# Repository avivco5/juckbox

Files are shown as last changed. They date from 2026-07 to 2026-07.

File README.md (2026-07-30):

# Juckbox

An open-source, standalone touchscreen jukebox built on an ESP32-S3. No WiFi, no phone, no router — everything is controlled directly on the device's touchscreen: browse songs from a microSD card, play them through a real I2S audio path, pick from 12 UI themes, and play a couple of built-in games (Pinball, Air Hockey) without interrupting the music.

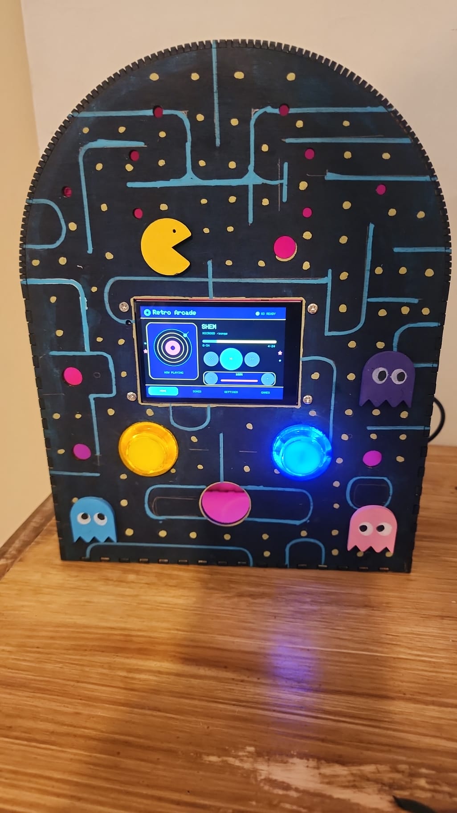
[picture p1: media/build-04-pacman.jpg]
Juckbox


This repository is the open-source release of the project: firmware, enclosure/cutting files, and a full bill of materials, so anyone can build their own.

## Repository layout

| Folder | Contents |
|---|---|
| [`firmware/`](firmware) | PlatformIO project — main ESP32-S3 firmware (display, touch, audio, songs, themes, games). Start here — see [firmware/README.md](firmware/README.md) for hardware pinout, build/flash instructions, and known limitations. |
| [`hardware/enclosure/`](hardware/enclosure) | 3D-printable/laser-cut enclosure files (`Cube.step`, `Cube.stl`, `jukebox.svg`) — base geometry generated with [Boxes.py](https://www.festi.info/boxes.py/), then modified |
| [`hardware/bom/`](hardware/bom) | Full bill of materials with AliExpress part links and prices — see [COMPONENTS.md](hardware/bom/COMPONENTS.md) for a plain-text version |
| [`extras/simon-says/`](extras/simon-says) | Standalone Simon Says PlatformIO project, a smaller side project built alongside the jukebox |
| [`design/`](design) | Concept art and case-design references used while designing the enclosure |
| [`ui-mockups/`](ui-mockups) | Standalone HTML previews of UI/theme mockups |
| [`media/`](media) | Photos and a demo video of finished builds |

## Gallery

Finished Pac-Man themed build, running with backlit arcade buttons

*Pac-Man theme, running*

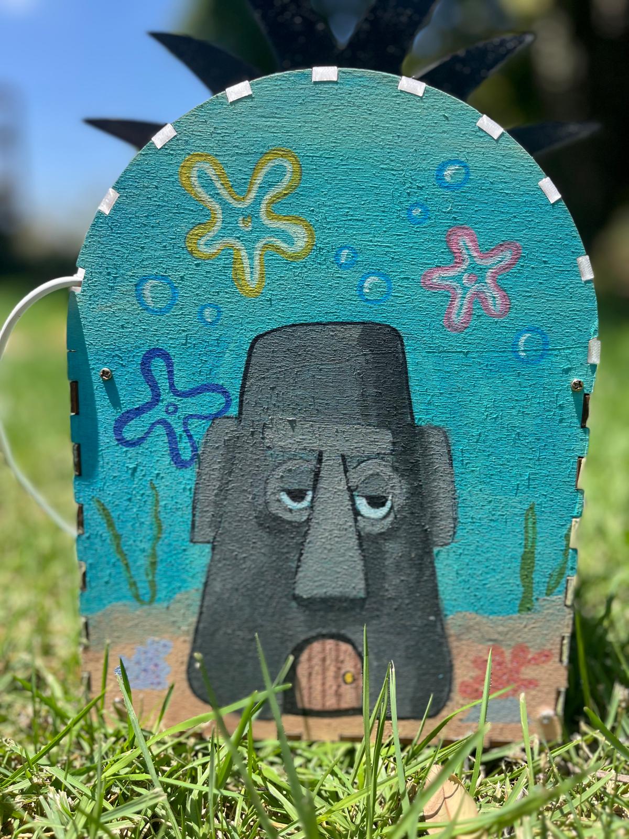
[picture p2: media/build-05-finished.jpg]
Finished build painted as Squidward's pineapple house


*Squidward's house theme*

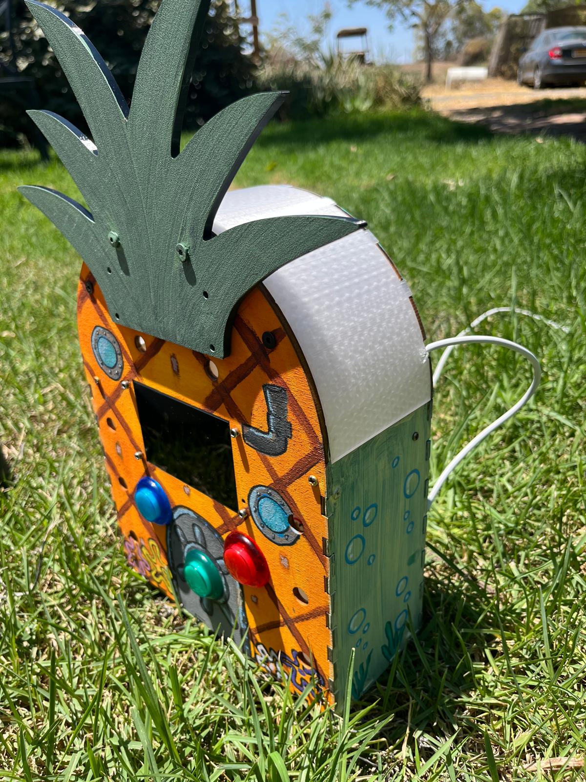
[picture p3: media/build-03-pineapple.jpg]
Pineapple-themed build in progress


*Pineapple theme, in progress*

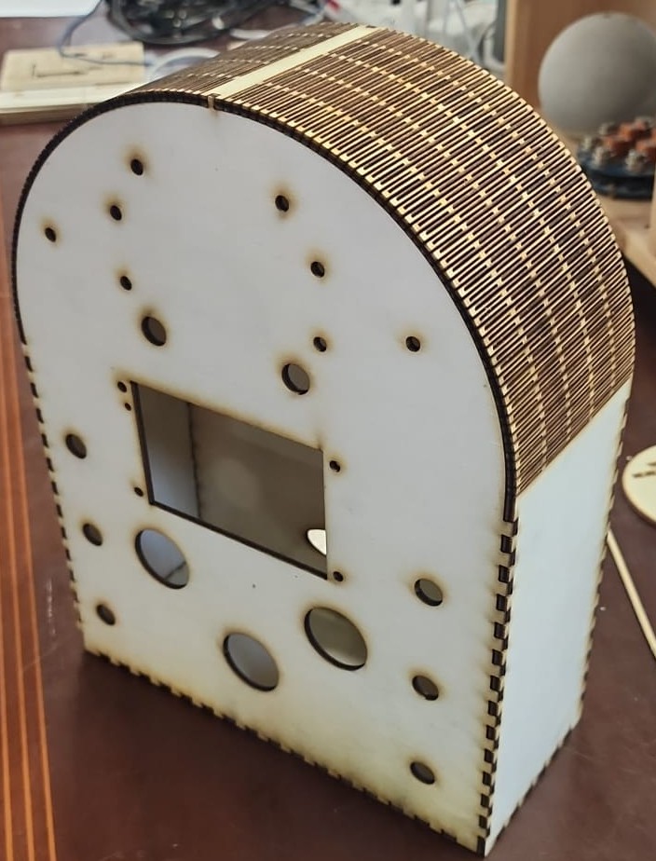
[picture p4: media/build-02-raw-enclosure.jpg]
Raw laser-cut enclosure before painting


*Raw laser-cut enclosure*

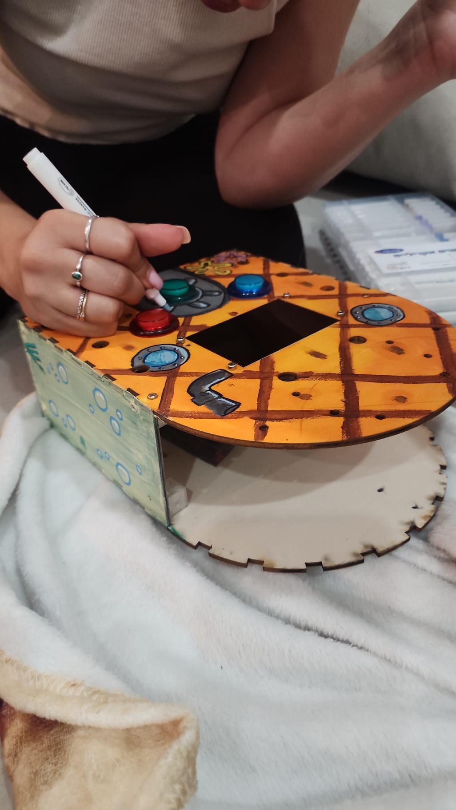
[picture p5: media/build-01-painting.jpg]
Hand-painting a laser-cut enclosure during a build workshop


*Painting at a build workshop*

### Demo video

[Watch the demo video](media/demo.mp4)

*(GitHub doesn't inline-embed video committed to a repo — click the image above, or go straight to [`media/demo.mp4`](media/demo.mp4), and GitHub's file viewer will play it.)*

## Getting started

1. Read [firmware/README.md](firmware/README.md) for the full hardware spec (ESP32-S3 module, display, touch, audio codec, SD card) and pin configuration.
2. Check [hardware/bom/](hardware/bom) for what to buy.
3. Print/cut the enclosure from [hardware/enclosure/](hardware/enclosure).
4. Build and flash the firmware with [PlatformIO](https://platformio.org/) — see the firmware README for exact steps.

## Affiliate Disclosure

Some purchase links in the [BOM](hardware/bom) may be AliExpress affiliate links (marked **Affiliate**). If you buy through a marked link, the project maintainer may receive a small commission at no additional cost to you. Affiliate links never change which component is recommended, and using them is entirely optional — every part in the BOM also lists its plain specification so you can search and buy it independently. See [hardware/bom/README.md](hardware/bom/README.md) for details.

## License

Licensed under the [GNU General Public License v3.0](LICENSE).

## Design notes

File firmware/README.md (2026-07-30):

# ESP32-S3 Touchscreen Jukebox

Standalone jukebox running on an ESP32-S3 with a 3.5" QSPI touchscreen, a microSD card slot, and a real I2S audio path (ES8311 codec + speaker amp). No WiFi, no phone, no router — everything is controlled directly on the device's touchscreen.

---

## What it does

| Feature | Status |
|---|---|
| Touchscreen UI (Home / Songs / Settings) | ✓ |
| List MP3 / WAV songs from SD card | ✓ |
| Play / Pause / Resume / Next / Previous | ✓ |
| Volume control (0–100, 5% steps) | ✓ |
| Real I2S audio playback (ES8311 codec) | ✓ |
| Elapsed-time / progress display (real song duration) | ✓ |
| Settings persist across power cycles (volume, repeat, shuffle, last song, theme) | ✓ |
| 12 selectable UI color themes, including a user-editable "Custom" theme (Settings → THEME) | ✓ |
| External PLAY/PAUSE and NEXT buttons | ✓ |
| RGB status LED (rainbow while playing, or always-on via Settings) | ✓ |
| Repeat (Off / One / All) and Shuffle | ✓ |
| Pinball + Air Hockey games (GAMES tab — no reflashing needed, music keeps playing) | ✓ |
| WiFi / web remote control | Removed (see [Legacy WiFi/Web Control](#legacy-wifiweb-control)) |
| Playlist support | Removed (see [Legacy WiFi/Web Control](#legacy-wifiweb-control)) |
| Physical buttons (MCP23017) | Future |

---

## Hardware

- ESP32-S3 development board with PSRAM (OPI, 8 MB embedded — N16R8 class module)
- 3.5" QSPI display, 480×320, ST77922-class panel controller
- Capacitive touch panel over I2C (CST9217/TDDI-style controller at address `0x55`)
- ES8311 I2C audio codec driving an I2S DAC path into a speaker amplifier
- MicroSD card (FAT32) wired in **SD_MMC 4-bit mode** (not SPI)

---

## Pin Configuration

Pins are currently **hardcoded per module** (display, touch, SD, audio each define their own pins at the top of their `.cpp` file) rather than centralized in `config.h` — see [Known Limitations](#known-limitations). To rewire the board, edit the file for the subsystem you're changing.

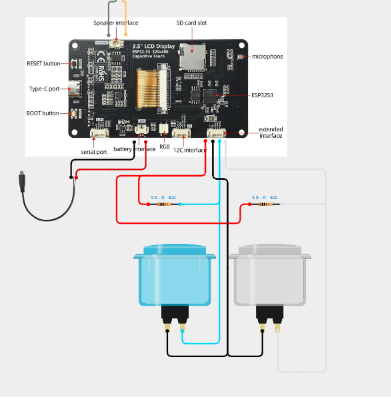
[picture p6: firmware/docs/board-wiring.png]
Board connector layout


### Display — QSPI ([src/DisplayDriver.cpp](src/DisplayDriver.cpp))

| Signal | GPIO |
|---|---|
| CS | 10 |
| CLK | 12 |
| D0 | 11 |
| D1 | 13 |
| D2 | 14 |
| D3 | 9  |
| Backlight | 41 |

### Touch — I2C ([src/TouchController.cpp](src/TouchController.cpp))

| Signal | GPIO |
|---|---|
| SDA | 38 |
| SCL | 39 |
| INT | 47 |
| RST | 48 |

I2C address: `0x55`. This bus is initialized once in `TouchController::begin()` and is reused by the ES8311 codec — `touchController.begin()` must run before `audioController.begin()` (already the case in [src/main.cpp](src/main.cpp)).

### SD Card — SD_MMC 4-bit ([src/SongLibrary.cpp](src/SongLibrary.cpp))

| Signal | GPIO |
|---|---|
| CLK  | 5 |
| CMD  | 4 |
| D0 | 6 |
| D1 | 7 |
| D2 | 2 |
| D3 | 3 |

### Audio — I2S + ES8311 codec ([src/JukeboxAudioOutput.cpp](src/JukeboxAudioOutput.cpp), [src/Es8311Codec.cpp](src/Es8311Codec.cpp))

| Signal | GPIO |
|---|---|
| MCLK | 17 |
| BCLK | 18 |
| WS | 21 |
| DOUT | 15 |
| PA enable | 1 (active-low) |

ES8311 codec I2C address: `0x18`. Codec is driven at 44.1 kHz / 16-bit stereo by default.

### External buttons ([src/main.cpp](src/main.cpp))

Both spare pins on the board's "Expansion Input Pins" connector (silkscreen IO45/IO46) are now used — IO38/39 are taken by the touch I2C bus, so there's nothing left over for a third button without an I2C GPIO expander (e.g. MCP23017 — see the "Future" row in the feature table above).

| Button | GPIO | Idle state | Wiring |
|---|---|---|---|
| PLAY/PAUSE | 46 | HIGH | Button to GND + **external ~10kΩ pull-up from GPIO46 to 3.3V** (GPIO46 is input-only with no internal pull-up — leaving this resistor out makes the pin float and read as repeated phantom presses) |
| NEXT | 45 | HIGH | Button to GND + **external ~10kΩ pull-up from GPIO45 to 3.3V** — wired the same way as PLAY/PAUSE on this build. **This is not the recommended wiring for this pin** — see the warning below. |

Both buttons use plain `INPUT` (not `INPUT_PULLUP`/`INPUT_PULLDOWN`) since neither pin's internal pull is reliable enough to depend on — the external resistor is mandatory, not optional, in both cases.

```
PLAY/PAUSE — GPIO46 (idle HIGH, pressed LOW)      NEXT — GPIO45 (idle HIGH, pressed LOW)
─────────────────────────────────────────────      ─────────────────────────────────────────────
                 3.3V                                                3.3V
                  │                                                   │
              ┌───┴───┐                                           ┌───┴───┐
              │ 10kΩ  │  external pull-up                         │ 10kΩ  │  external pull-up
              └───┬───┘                                           └───┬───┘
                  ├───────────────► GPIO46 (ESP32-S3, INPUT)          ├───────────────► GPIO45 (ESP32-S3, INPUT)
                  │                                                   │
              ┌───┴───┐                                           ┌───┴───┐
              │button │                                           │button │
              └───┬───┘                                           └───┬───┘
                  │                                                   │
                 GND                                                 GND
```

> **⚠️ Boot-reliability warning:** GPIO45 is sampled by the ESP32-S3's ROM bootloader at power-on to select flash voltage (3.3V vs 1.8V), and is *supposed* to idle LOW to avoid loading that strap — that's why earlier versions of this doc (and the code) had it wired with a **pull-down** instead (button to 3.3V, resistor to GND, idle LOW/press HIGH). This build wires it as pull-up instead (idle HIGH), matching the diagram above, because that's how the hardware was actually built. The firmware's button-reading code has been updated to match (`pressed = digitalRead(...) == LOW` for both buttons now — see `main.cpp`, `PinballMain.cpp`, `AirHockeyMain.cpp`), but **that's a software accommodation, not a fix for the underlying boot-strap risk**: the pin's voltage at boot is a hardware fact the bootloader reads before any of this code runs. If you see occasional failed/garbled boots, rewiring GPIO45 back to pull-down (and reverting the `== LOW` back to `== HIGH` for that pin in the three files above) is the actual fix.

### RGB status LED ([src/StatusLed.cpp](src/StatusLed.cpp))

| Signal | GPIO |
|---|---|
| Onboard RGB LED (WS2812-style, single data line) | 40 |

This pin is **not documented anywhere by the vendor** — it was found by physically probing the board with [src/RgbPinFinder.cpp](src/RgbPinFinder.cpp) (a one-off diagnostic, see its own PlatformIO env below). By default (`LedMode::WhenPlaying`) the LED cycles through a rainbow while a song is playing and turns off otherwise; the Settings page's **LED** toggle switches to `LedMode::Always` so it keeps cycling even when paused/stopped. Persisted as `ledmode=0/1` in `jukebox_settings.cfg`.

> Don't trust GPIO22/23/24/25 as candidates for anything — they don't physically exist on this ESP32-S3 chip (confirmed by hardware errors when tested). Don't assume GPIO48 drives the LED either — it matches the generic Arduino-ESP32 `esp32-s3-devkitc-1` board profile's default NeoPixel pin, but on this board GPIO48 is already the touch controller's reset line, confirmed unrelated to the LED.

---

## SD Card Folder Structure

```
SD card root/
├── songs/
│   ├── 001.mp3
│   ├── 002.wav
│   └── ...
└── jukebox_settings.cfg
```

`/songs` is created automatically on first boot if it doesn't exist. Only `.mp3` and `.wav` files are listed; the on-screen title is the filename without its extension.

`jukebox_settings.cfg` is a small plain-text key=value file (no JSON dependency) written by [src/JukeboxUI.cpp](src/JukeboxUI.cpp) whenever volume, repeat mode, shuffle, the selected song, theme, or LED mode changes, and read back on boot. The last song is only *selected*, never auto-played, on startup.

Song duration shown on the Home page and used for the progress bar is computed once per song during `SongLibrary::scan()` ([src/SongLibrary.cpp](src/SongLibrary.cpp)): exact for WAV (parsed from the `fmt`/`data` RIFF chunks), and an estimate for MP3 (file size ÷ bitrate of the first frame, assuming constant bitrate — will be off for VBR-encoded files since there's no Xing/VBRI header parsing).

---

## Install PlatformIO

1. Install [VS Code](https://code.visualstudio.com/)
2. Open Extensions → search `PlatformIO IDE` → Install
3. Restart VS Code

Or use the CLI:
```bash
pip install platformio
```

---

## Build and Upload

Open the `CODE/` folder in VS Code with PlatformIO, or use the terminal:

```bash
# Compile only (check for errors)
pio run

# Compile and upload firmware to the ESP32-S3
pio run --target upload

# Open Serial Monitor
pio device monitor
```

There is no web UI to upload anymore — `board_build.filesystem = littlefs` in `platformio.ini` and the `data/` folder are leftovers from the previous WiFi-controlled version and are not used by the current firmware (see below).

There are also alternate PlatformIO environments that build completely separate firmware images sharing only [src/DisplayDriver.cpp](src/DisplayDriver.cpp) — `rgb_finder` and `diagtest` are flashed *instead of* the jukebox (re-flash `esp32s3` afterwards to get it back):

```bash
pio run -e rgb_finder -t upload   # one-off: discover the RGB LED's GPIO (see above)
pio run -e diagtest -t upload     # assembly diagnostic: SD/song list + button press states
pio run -e pinball -t upload      # standalone pinball "cartridge" — not needed if you just want the GAMES tab
pio run -e airhockey -t upload    # standalone air hockey "cartridge" — same idea
pio run -e esp32s3 -t upload      # flash the real jukebox firmware again afterwards
```

### Games ([src/PinballGame.h](src/PinballGame.h) / [src/AirHockeyGame.h](src/AirHockeyGame.h))

Each game is playable two ways from the exact same code:

1. **From inside the jukebox** — the **GAMES** tab (see below), no reflashing needed. Music keeps playing in the background (`AudioController` isn't touched), since only the display and these two buttons are repurposed while a game is running.
2. **Standalone firmware** (`pio run -e pinball -t upload` / `-e airhockey -t upload`) — a dedicated "arcade cabinet" image with nothing else on it, for when you don't want the jukebox at all. Re-flash `esp32s3` afterward to get it back.

Both entry points per game (e.g. [src/PinballMain.cpp](src/PinballMain.cpp) for the standalone build, `JukeboxUI`'s `Page::Pinball` for the tab) just drive the same game class — the physics/rendering exist in exactly one place. `JukeboxUI::setButtonA()`/`setButtonB()` dispatch the two physical buttons to whichever game is currently active (`main.cpp` doesn't know or care which game that is).

**Pinball** — PLAY/PAUSE (IO46) = left flipper, NEXT (IO45) = right flipper. 3 balls per game; bumpers are worth 100 points each. When a ball drains past both flippers, the next one serves automatically; after the third, it's Game Over — press either button to restart.

**Air Hockey** — PLAY/PAUSE (IO46) = paddle up, NEXT (IO45) = paddle down, against a simple CPU-controlled opponent paddle. First to 5 points wins; press either button to restart after Game Over.

Both use simple fixed-timestep 2D physics (gravity/collision reflection for pinball, paddle-angle deflection for air hockey), not a physics engine — deliberately kept simple since [DisplayDriver::flush()](src/DisplayDriver.cpp) always pushes the *entire* 480×320 framebuffer (no partial/dirty-rect updates), which caps real-world frame rate at roughly 20–30 FPS regardless of how little changed — plenty for this kind of game, but a reason not to expect smooth 60 FPS on this display.

When played from the **GAMES** tab, an on-screen **EXIT** button (top-right) returns to the jukebox — the physical buttons can't do it themselves since they're busy being game controls while a game is running.

---

## Using the Touchscreen UI

The UI has four tabs along the bottom: **HOME**, **SONGS**, **SETTINGS**, **GAMES**.

- **HOME** — shows the current song, play/pause state, elapsed time, and has previous/play-pause/next buttons plus a volume +/- control.
- **SONGS** — paginated list (4 per page) of everything found in `/songs`. Tap a row to select and start playing it; tap **SCAN** to re-read the SD card after adding files; use `<` / `>` to page through the list.
- **SETTINGS** — a **REPEAT** button (tap to cycle OFF → ONE → ALL), a **SHUFFLE** toggle, and an **LED** toggle (AUTO = rainbow only while a song plays, the original behavior; ALWAYS = rainbow runs continuously even when paused/stopped); a **THEME** row with `<`/`>` arrows flanking it (step through themes one at a time, same as the Theme Menu's edge buttons) — tapping the theme name itself opens the full picker (see below). No volume control here — that's on **HOME** only, to leave more room for these.
- **GAMES** — **PINBALL** and **AIR HOCKEY** (see above). While a game is running, the jukebox's normal UI (top bar, bottom nav, themes) is replaced entirely by the game's own full-screen display; PLAY/PAUSE and NEXT become game controls instead of playback controls until you tap **EXIT**.

Repeat/shuffle only affect what happens automatically when a song finishes on its own (not the manual `<<`/`>>` buttons, which always go sequentially): **Repeat: One** replays the same song forever; **Repeat: All** advances to the next song (sequential, or random if Shuffle is on) and never stops on its own; **Repeat: Off** with Shuffle on still jumps to a random song when one ends; **Repeat: Off** with Shuffle off just stops, like before this feature existed.

Touch input is debounced in [src/main.cpp](src/main.cpp) to work around a touch-controller quirk where some CST9217/TDDI firmware revisions keep reporting the last coordinate after release; repeated taps are re-armed by time and by a "moved to a different control" check.

### Theme System

Tapping the bottom row of the **SETTINGS** page (labeled `THEME: <name>`) opens a scrollable **Choose Theme** screen listing all 12 themes; tapping a row applies it immediately and returns to Settings. The bottom nav bar stays visible on this screen too, so tapping **HOME**/**SONGS**/**SETTINGS** also exits it. Two arrow pills on the left/right edges of the screen step through themes one at a time (wrapping around) and apply instantly, for quickly browsing/previewing — the on-screen list auto-scrolls to keep the current pick visible.

- **Where themes are defined**: [src/Theme.h](src/Theme.h) / [src/Theme.cpp](src/Theme.cpp). Each themed design is six hand-picked colors (`background`, `panel`, `title`, `text`, `selected`, `border`); the rest of the palette (raised-surface tint, muted text, dark button text) is derived once at theme-switch time by `ThemeManager::buildDefinitions()`, so adding a new design theme only means one `makeTheme(...)` call. The exception is **Classic** — the app's original hand-tuned color scheme from before the theme system existed, kept as its own option since all nine of its colors are specified directly via `makeRawTheme(...)` rather than derived. New themes must be appended right before `THEME_COUNT` in `Theme.h`, never inserted earlier — the theme index is what's persisted to disk, so reordering existing entries would silently reassign everyone's saved theme.
- **Adding a static theme (the exercise for trainees)**: add one enum value right before `THEME_COUNT` in `Theme.h`, then one `makeTheme("Name", "Title Text", bg, panel, title, text, selected, border)` call in `ThemeManager::buildDefinitions()` in `Theme.cpp`. That's the entire change — `JukeboxUI.cpp` doesn't need to be touched, since every screen already reads colors through `themeManager.colors()`.
- **Custom theme (Settings → THEME → Custom row → EDIT)**: the one theme whose colors are chosen on-device instead of hardcoded. The editor screen (`JukeboxUI::drawThemeEditor`) shows the 6 color roles, each cycling through a shared 14-color swatch list (`kThemeSwatches` in `Theme.h`) via `<`/`>` — no free-form color picker, to keep the touch UI simple and stable. Selecting Custom applies it immediately (`ThemeManager::setCustomColors`, rebuilt the same way as any other theme) and every change is saved right away as `custom_bg`/`custom_panel`/`custom_title`/`custom_text`/`custom_selected`/`custom_border` (hex) in `jukebox_settings.cfg`, so it's remembered across restarts.
- **Default theme**: `ThemeManager::begin()` in `Theme.cpp` sets `_current = THEME_PINEAPPLE`. Change that line to change the factory default.
- **Persistence**: the selected theme is saved as `theme=<index>` in `jukebox_settings.cfg` alongside volume/repeat/shuffle (see `JukeboxUI::loadSettings()`/`saveSettings()`), so it survives power cycles.
- **Scope**: colors change everywhere via `themeManager.colors()`, plus small decorative accents on the **Home** page only (`JukeboxUI::drawThemeDecorations`) — no per-theme fonts or animations, so every theme stays equally fast and memory-safe. Each of the 10 box-design themes gets a matching 16×16 pixel-art icon (pineapple, star, robot head, rocket, skull, speaker, cassette, tree, gear, monster face — `iconPineapple`/`iconStar`/etc. in `JukeboxUI.cpp`), drawn twice (left of the album-art panel, right of the volume panel) via `Arduino_GFX::drawBitmap()`, recolored per theme by passing `theme.accent` as the draw color. A couple of themes add a tiny extra accent dot (bubble/coin/spark) from the remaining primitive helpers (`drawBubble`/`drawDot`/`drawCoin`). **Classic** and **Custom** intentionally have no icon — there's no fixed "vibe" to draw for either.
- **Where the icons come from**: hand-drawn with a one-off Pillow (Python) script — draw simple vector shapes (circle/polygon/line) at 160×160, downsample to 16×16 with Lanczos resampling, threshold to 1-bit. Not sourced from image files, so there's no asset pipeline to maintain; each icon is a 32-byte `static const uint8_t[]` array (1bpp, MSB-first, byte-packed rows — the exact format `drawBitmap()` expects). All 10 icons together cost ~320 bytes of flash. To change or add an icon, regenerate with the same technique (or hand-edit the hex bytes — each row is 2 bytes for 16 columns) and add a case to the `icon = ...` switch in `drawThemeDecorations()`.
- **Adapting the spec's button mapping**: the original theme-menu spec assumed physical NEXT/BACK/PLAY/SELECT buttons with long-press gestures. This hardware only has two buttons (PLAY/PAUSE on GPIO46, NEXT on GPIO45 — see [Pin Configuration](#pin-configuration)), both wired globally to playback in `main.cpp`. Rather than overload them with menu-navigation meaning, the theme menu is touch-only, reached from Settings as described above.

### Touch reliability — diagnostics only (active "fix" reverted)

The touch controller and the ES8311 audio codec share one I2C bus (GPIO38/39), and touch occasionally stops responding for no obvious reason. A first attempt at fixing this (I2C bus recovery + a periodic preventive rearm every 30s) made things **worse** — `Wire.begin()` isn't cheap, and re-running it on every accepted touch destabilized the I2C driver itself. That attempt was reverted.

What's left, in [src/TouchController.cpp](src/TouchController.cpp), is **passive only**: `readRegister()` logs `[Touch] I2C read failing` / `[Touch] I2C read recovered after N failed attempt(s)` on state transitions (not every poll, so it won't flood the log). If touch stops responding again, check the serial log for these messages — that'll tell us whether it's really an I2C-level failure before trying another fix.

---

## Known Limitations

- `src/config.h` is **not included by any file in the active build** (`platformio.ini`'s `build_src_filter`). All real pin/volume/storage constants are hardcoded in the relevant driver `.cpp` files instead — `config.h` is stale and should not be trusted as the source of truth for pins.
- No authentication or remote control of any kind — the device is controlled only via its own touchscreen.
- `next` / `previous` always wrap around the full song list found by the last `SCAN`; there's no shuffle or playlist concept anymore.
- Long song titles are truncated with `...` on screen; no Hebrew/RTL text rendering is attempted (the on-device UI is Latin/numeric only — Hebrew RTL lived in the removed web UI, see below).
- The RGB LED's color/brightness/animation speed are fixed constants in `StatusLed.cpp`, not exposed in the Settings UI.

---

## Legacy WiFi/Web Control

This repository still contains an earlier version of the jukebox that exposed a WiFi access point and a Hebrew RTL web UI (`/api/...` JSON endpoints, file upload, playlists):

- [src/WebServerManager.h](src/WebServerManager.h) / [.cpp](src/WebServerManager.cpp)
- [src/StorageManager.h](src/StorageManager.h) / [.cpp](src/StorageManager.cpp)
- [src/PlaylistManager.h](src/PlaylistManager.h) / [.cpp](src/PlaylistManager.cpp)
- [data/index.html](data/index.html), [data/app.js](data/app.js), [data/style.css](data/style.css)

**These files are excluded from the build** via `build_src_filter` in `platformio.ini` and are **bit-rotted**: they call `AudioController` methods (`getCurrentSong()`, `getVolume()`, `next()`, `previous()`) that no longer exist on the current `AudioController` (which was rewritten for real I2S/ES8311 playback), and they depend on `ESPAsyncWebServer`/`ArduinoJson`, which are no longer listed in `lib_deps`. They're kept around for reference only — reviving WiFi control would mean re-wiring them against the current `AudioController` API and adding the libraries back.

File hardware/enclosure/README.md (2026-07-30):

# Enclosure

3D-printable/laser-cut enclosure files: `Cube.step`, `Cube.stl`, `jukebox.svg`.

## Credit

Enclosure base geometry was generated using [Boxes.py](https://www.festi.info/boxes.py/), and was subsequently modified for the ESP32 Jukebox project.

Boxes.py is licensed under the GNU General Public License v3.0 or later. See [THIRD_PARTY_NOTICES.md](THIRD_PARTY_NOTICES.md) for the full notice.

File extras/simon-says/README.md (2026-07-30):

# Simon Says — ESP32-2432S028 (CYD)

A complete Simon Says memory game for the Cheap Yellow Display (ESP32-2432S028).

---

## Hardware target

| Item | Value |
|---|---|
| Board | ESP32-2432S028 ("Cheap Yellow Display") |
| MCU | ESP32 |
| Display | 2.8 inch ILI9341, 320 × 240, landscape |
| Touch | XPT2046 resistive, separate SPI bus |
| Framework | Arduino (PlatformIO) |

---

## Project structure

```
SimonSays/
├── platformio.ini          project / build config
├── include/
│   └── User_Setup.h        TFT_eSPI pin config (keeps library folder clean)
├── src/
│   ├── config.h            all pins, calibration, layout constants
│   ├── main.cpp            setup(), loop(), state machine
│   ├── game.h / game.cpp   sequence logic, scoring, NVS high score, sound stubs
│   ├── ui.h  / ui.cpp      all drawing: screens, buttons, status bar
│   └── touch.h / touch.cpp XPT2046 init, coordinate mapping, button detection
└── README.md
```

---

## Required libraries

PlatformIO fetches these automatically from `lib_deps` in `platformio.ini`:

| Library | Author | Purpose |
|---|---|---|
| TFT_eSPI | Bodmer | ILI9341 display driver |
| XPT2046_Touchscreen | Paul Stoffregen | Resistive touch controller |
| Preferences | ESP32 Arduino core | NVS high-score storage (built-in, no entry needed) |

---

## How to upload with PlatformIO

1. Install [VS Code](https://code.visualstudio.com/) and the **PlatformIO IDE** extension.
2. Open the `SimonSays/` folder in VS Code (`File → Open Folder`).
3. Connect the CYD via USB.
4. Click **Upload** (→ arrow in the PlatformIO toolbar) or run:
   ```
   pio run --target upload
   ```
5. Open **Serial Monitor** at 115200 baud if you need to read debug output.

---

## Game controls

| Element | Action |
|---|---|
| START button (title screen) | Go to difficulty picker |
| EASY / NORMAL / HARD | Start game at that speed |
| Four large coloured buttons | Repeat the sequence |
| PLAY AGAIN (game-over screen) | Return to difficulty picker |

Difficulty flash speeds:

| Difficulty | Button lit | Gap between steps |
|---|---|---|
| Easy | 700 ms | 400 ms |
| Normal | 450 ms | 250 ms |
| Hard | 250 ms | 150 ms |

---

## Touch calibration

### Quick calibration procedure

1. Open `src/config.h` and set `DEBUG_TOUCH 1`.
2. Upload and open Serial Monitor (115 200 baud).
3. Touch the **four corners** of the screen one at a time; note the raw `x` and `y` values printed.
4. Update the four constants:
   ```c
   #define TOUCH_X_MIN   <left-edge raw value>
   #define TOUCH_X_MAX   <right-edge raw value>
   #define TOUCH_Y_MIN   <top-edge raw value>
   #define TOUCH_Y_MAX   <bottom-edge raw value>
   ```
5. If touching the left side registers as right (or vice versa), set `TOUCH_INVERT_X 1`.
6. If touching the top registers as bottom (or vice versa), set `TOUCH_INVERT_Y 1`.
7. If X and Y raw values are completely swapped for your revision, set `TOUCH_SWAP_XY 1`.
8. Set `DEBUG_TOUCH 0` when done.

---

## Adding a buzzer (optional)

1. Connect a **passive buzzer** between **GPIO 26** and **GND** (GPIO 26 is the DAC/`tone()` capable pin on CYD).
2. Set `BUZZER_ENABLED 1` in `src/config.h`.
3. Uncomment the `tone()` lines inside `playToneForButton()`, `playErrorTone()`, and `playSuccessTone()` in `src/game.cpp`.

---

## Common issues and fixes

### White screen / blank screen

- **Cause**: TFT_eSPI is using wrong pins.
- **Fix**: Confirm `include/User_Setup.h` is present in the `include/` folder and that PlatformIO finds it. Run `pio run -v` and look for the include path; `include/` must appear before the TFT_eSPI library path.
- **Also check**: `ILI9341_DRIVER` is defined and no other driver is defined in `User_Setup.h`.

### Screen mirrored or rotated wrong

- **Fix**: Change `SCREEN_ROTATION` in `src/config.h`.
  - `1` = landscape, USB on the left
  - `3` = landscape, USB on the right
  - `0` = portrait
  - `2` = portrait flipped

### Touch coordinates are completely wrong or reversed

- Enable `DEBUG_TOUCH 1` and check the raw values.
- Adjust `TOUCH_X_MIN/MAX` and `TOUCH_Y_MIN/MAX`.
- If axes are swapped: `TOUCH_SWAP_XY 1`.
- If an axis is mirrored: `TOUCH_INVERT_X 1` or `TOUCH_INVERT_Y 1`.

### Backlight not turning on

- The backlight is driven by GPIO 21 (`TFT_BL_PIN` in `config.h`).
- `initDisplay()` calls `pinMode(TFT_BL_PIN, OUTPUT)` and `digitalWrite(TFT_BL_PIN, HIGH)`.
- If still dark, measure the pin voltage with a multimeter while running; if it reads 3.3 V the issue is the backlight circuit (some boards need an inverted signal — change `HIGH` to `LOW` in `ui.cpp`).

### Wrong board revision — different pin numbers

- All pins are in `src/config.h` (one place to change).
- `include/User_Setup.h` mirrors the display pins for TFT_eSPI — keep them in sync if you change them.

### Compile error: "User_Setup.h: No such file"

- Confirm `include/User_Setup.h` exists in the `SimonSays/include/` folder.
- Confirm `platformio.ini` has `-I include` in `build_flags`.

### Touch works but buttons in wrong quadrant

- The button boundaries are computed from `BTN_W`, `BTN_H`, and `STATUS_BAR_H` in `config.h` from the same values used to draw them, so this almost always means the touch calibration needs adjustment (see above).

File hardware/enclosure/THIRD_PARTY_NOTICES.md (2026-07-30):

# Third-Party Notices

## Boxes.py

Some enclosure geometry was initially generated using Boxes.py.

Project: Boxes.py
Author and contributors: Florian Festi and contributors
License: GNU General Public License v3.0 or later

The generated files were modified and adapted for this project.
No Boxes.py source code is included in this repository.

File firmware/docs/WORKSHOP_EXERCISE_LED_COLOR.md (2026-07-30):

# תרגיל סדנה: בחירת צבע קבוע ל-LED במקום קשת בענן

## המטרה

כרגע, ה-LED הצבעוני (RGB) שדולק בזמן נגינה (או תמיד, אם מצב ה-LED ב-SETTINGS מוגדר ל-ALWAYS) עושה **קשת בענן** — משנה צבע ברציפות. במשימה הזו נחליף את זה **לצבע קבוע אחד לבחירתכם**.

לא נוגעים במתי ה-LED דולק (זה כבר מוגדר ב-SETTINGS ← LED, AUTO/ALWAYS), רק **באיזה צבע** הוא דולק.

---

## רקע: איפה זה מוגדר

קובץ אחד בלבד מעורב: **`src/StatusLed.cpp`**, בפונקציה `update()`:

```cpp
void StatusLed::update()
{
    if (!_pixel)
    {
        return;
    }

    if (_mode == LedMode::Always || audioController.isPlaying())
    {
        _hue += HueStepPerTick;
        _pixel->setPixelColor(
            0,
            _pixel->gamma32(_pixel->ColorHSV(_hue)));
    }
    else
    {
        _pixel->setPixelColor(0, 0);
    }
    _pixel->show();
}
```

השורה `_hue += HueStepPerTick;` מקדמת את הצבע קדימה בכל "טיק" (כל קריאה ל-`update()`, שקורה כל הזמן בלולאה הראשית) — זה מה שיוצר את אפקט קשת-בענן. השורה `_pixel->ColorHSV(_hue)` הופכת את הערך המתקדם הזה לצבע בפועל.

---

## ⚠️ שימו לב: זה **לא** אותו פורמט צבע כמו במסך!

בתרגילים הקודמים (למשל צבעי המחבטים בהוקי אוויר) השתמשנו בפורמט **RGB565** — מספר אחד ארוז (`0x07FF` וכו') עבור המסך.

ה-LED כאן הוא **NeoPixel (WS2812)**, שמשתמש בפורמט אחר לגמרי: **שלושה מספרים נפרדים**, אחד לכל ערוץ (אדום, ירוק, כחול), כל אחד בין **0 ל-255**. אין קשר בין שני הפורמטים — זו הזדמנות טובה להבין שלא כל רכיב חומרה "מדבר" באותה שפת צבעים.

---

## שלב 1 — בחרו צבע קבוע

פתחו את `src/StatusLed.cpp`. מצאו את השורות:

```cpp
_pixel->setPixelColor(
    0,
    _pixel->gamma32(_pixel->ColorHSV(_hue)));
```

והחליפו אותן ב:

```cpp
_pixel->setPixelColor(
    0,
    _pixel->gamma32(_pixel->Color(255, 0, 0)));
```

(הדוגמה למעלה היא אדום מלא. שנו את שלושת המספרים לצבע שאתם רוצים — ראו טבלה למטה.)

**את השורה `_hue += HueStepPerTick;` שמעליה אין צורך למחוק** — היא פשוט תפסיק להיות בשימוש בפועל, וזה בסדר גמור.

---

## טבלת צבעים מוכנה להעתקה (פורמט R, G, B — כל ערך 0–255)

| צבע | קוד להעתקה |
|---|---|
| אדום | `255, 0, 0` |
| ירוק | `0, 255, 0` |
| כחול | `0, 0, 255` |
| צהוב | `255, 255, 0` |
| ורוד | `255, 0, 150` |
| כתום | `255, 100, 0` |
| טורקיז | `0, 255, 200` |
| סגול | `150, 0, 255` |
| לבן | `255, 255, 255` |

---

## שלב 2 — קומפילציה, העלאה, ובדיקה

1. שמרו את הקובץ.
2. הריצו `pio run -e esp32s3` ובדקו שאין שגיאות קומפילציה.
3. אם הכול תקין: `pio run -e esp32s3 -t upload` כדי להעלות לבקר.
4. **בדיקה בפועל**: לכו ל-SETTINGS ← LED, הגדירו ALWAYS (כדי לראות את ה-LED דולק גם בלי נגינה), ותראו את הצבע הקבוע שבחרתם במקום קשת הבענן.

---

## אתגר בונוס (לא חובה)

1. **מהירות קשת בענן**: אם דווקא אהבתם את קשת הבענן ורק רוצים לשנות את המהירות שלה — במקום להחליף ל-`Color()` קבוע, שנו את הערך של `HueStepPerTick` בראש הקובץ (מספר גדול יותר = קשת מהירה יותר, מספר קטן יותר = איטית יותר).
2. **אתגר מתקדם**: לנסות לגרום לצבע ה-LED להשתנות לפי **עוצמת הווליום** הנוכחית (רמז: יש ל-`AudioController` דרך לבדוק את הווליום הנוכחי — חפשו איך `JukeboxUI` משתמש בזה כדי להציג את אחוז הווליום על המסך, ותצטרכו למצוא דרך דומה לגשת אליו מתוך `StatusLed`).

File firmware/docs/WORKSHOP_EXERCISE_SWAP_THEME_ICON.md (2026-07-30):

# תרגיל סדנה: החלפת אייקון לערכת נושא קיימת

## המטרה

לג'וקבוקס יש 10 ערכות נושא (Themes), וכל אחת מהן מציגה אייקון קטן (16x16 פיקסלים) בשוליים של מסך ה-HOME, בצבע הערכה. במשימה הזו נחליף לערכה אחת את האייקון שלה **באייקון של ערכה אחרת** — לדוגמה, לתת לערכת "Pineapple" (אננס) אייקון של גולגולת במקום אננס — רק בשביל הכיף, ולראות מה קורה.

לא נוגעים בצבעים או בשם הערכה, רק באייקון.

---

## רקע: איפה זה מוגדר

קובץ אחד בלבד מעורב: **`src/JukeboxUI.cpp`**, בפונקציה `drawThemeDecorations()` (בערך שורות 1009–1022):

```cpp
const uint8_t* icon = nullptr;
switch (themeManager.current())
{
    case THEME_PINEAPPLE: icon = iconPineapple; break;
    case THEME_RETRO_ARCADE: icon = iconStar; break;
    case THEME_ROBOT: icon = iconRobot; break;
    case THEME_SPACESHIP: icon = iconSpaceship; break;
    case THEME_PIRATE: icon = iconSkull; break;
    case THEME_VINTAGE_RADIO: icon = iconSpeaker; break;
    case THEME_CASSETTE: icon = iconCassette; break;
    case THEME_FOREST: icon = iconTree; break;
    case THEME_STEAMPUNK: icon = iconGear; break;
    case THEME_MONSTER: icon = iconMonster; break;
    default: break;  // Classic, Custom: no icon
}
```

זה בעצם "טבלת התאמה" פשוטה: כל שורה אומרת "ערכת נושא X מקבלת אייקון Y". **10 האייקונים כבר קיימים** באותו קובץ (בערך שורות 61–70) בתור מערכים בשם `iconPineapple`, `iconStar`, `iconRobot`, `iconSpaceship`, `iconSkull`, `iconSpeaker`, `iconCassette`, `iconTree`, `iconGear`, `iconMonster` — אין צורך ליצור אייקון חדש, רק לבחור אחד קיים.

---

## שלב 1 — בחרו ערכה ואייקון חדש בשבילה

פתחו את `src/JukeboxUI.cpp`, מצאו את הבלוק שלמעלה, ובחרו שורה אחת לשנות. לדוגמה, נחליף את האייקון של Pineapple מאננס לגולגולת:

**לפני:**
```cpp
case THEME_PINEAPPLE: icon = iconPineapple; break;
```

**אחרי:**
```cpp
case THEME_PINEAPPLE: icon = iconSkull; break;
```

(שינוי רק את החלק שאחרי ה-`=` — לא את `case THEME_PINEAPPLE`, ולא את ה-`;` בסוף.)

אפשר כמובן לבחור כל צירוף שרוצים — כל ערכה מותר לה כל אייקון מ-10 הרשימה, גם אייקון ששייך במקור לערכה אחרת.

---

## שלב 2 — קומפילציה, העלאה, ובדיקה

1. שמרו את הקובץ.
2. הריצו `pio run -e esp32s3` ובדקו שאין שגיאות קומפילציה.
3. אם הכול תקין: `pio run -e esp32s3 -t upload` כדי להעלות לבקר.
4. **בדיקה בפועל**: לכו למסך ה-HOME, פתחו את תפריט הערכות (SETTINGS ← THEME) ובחרו את הערכה ששיניתם — האייקון החדש אמור להופיע משני צידי המסך (שוליים שמאל וימין, ליד אזור הכפתורים).

---

## אתגר בונוס (לא חובה)

1. **החלפה כפולה**: תחליפו בין שני אייקונים — למשל תנו ל-Robot את האייקון של Monster, ול-Monster את האייקון של Robot — ותראו את שתי הערכות "מחליפות זהות".
2. **אתגר מתקדם**: מי שרוצה אתגר אמיתי — לנסות לצייר אייקון חדש משלכם! כל אייקון הוא בעצם רשת של 16x16 פיקסלים, כל אחד דלוק (1) או כבוי (0), ארוזה כזוג בייטים לכל שורה (32 בייטים סה"כ לאייקון). זה מסובך יותר ודורש הבנה של מספרים בינאריים/הקסדצימליים — שאלו את המדריך/ה אם אתם רוצים לנסות.

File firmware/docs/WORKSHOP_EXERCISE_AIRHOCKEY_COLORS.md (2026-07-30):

# תרגיל סדנה: שינוי צבעי המחבטים במשחק הוקי אוויר

## המטרה

לשנות את הצבעים של שני המחבטים (הלוחות) במשחק **הוקי אוויר** — המחבט של השחקן (שמאל) והמחבט של המחשב (ימין) — לצבעים לבחירתכם.

לא נוגעים בפיזיקה או בניקוד, רק בצבע.

---

## רקע: איפה הצבעים מוגדרים

קובץ אחד בלבד מעורב: **`src/AirHockeyGame.cpp`**.

בראש הקובץ (בערך שורות 31–39) מוגדרת רשימת כל הצבעים במשחק:

```cpp
constexpr uint16_t ColorBg = 0x0844;
constexpr uint16_t ColorWall = 0x39C7;
constexpr uint16_t ColorPuck = 0xFFE0;
constexpr uint16_t ColorPlayerPaddle = 0x07FF;
constexpr uint16_t ColorCpuPaddle = 0xF800;
constexpr uint16_t ColorText = 0xF7BE;
constexpr uint16_t ColorMuted = 0x8410;
constexpr uint16_t ColorWin = 0x07E0;
constexpr uint16_t ColorLose = 0xF800;
```

השורות שמעניינות אותנו:

```cpp
constexpr uint16_t ColorPlayerPaddle = 0x07FF;  // המחבט של השחקן (טורקיז/ציאן)
constexpr uint16_t ColorCpuPaddle = 0xF800;     // המחבט של המחשב (אדום)
```

השמות `ColorPlayerPaddle` ו-`ColorCpuPaddle` משמשים בהמשך הקובץ (בפונקציה `draw()`, בערך שורות 213–214) כדי לצייר את שני המחבטים בפועל — **אין צורך לגעת שם**, מספיק לשנות את הערך כאן, למעלה, ושני הציורים יתעדכנו אוטומטית.

---

## שלב 1 — שנו את צבע המחבט של השחקן

פתחו את `src/AirHockeyGame.cpp`. מצאו את השורה:

```cpp
constexpr uint16_t ColorPlayerPaddle = 0x07FF;
```

והחליפו את `0x07FF` בערך צבע אחר מהטבלה למטה (או בערך משלכם — ראו הסבר בסוף).

## שלב 2 — שנו את צבע המחבט של המחשב

באותו קובץ, מצאו את השורה:

```cpp
constexpr uint16_t ColorCpuPaddle = 0xF800;
```

והחליפו את `0xF800` בערך אחר מהטבלה.

**טיפ:** כדאי לבחור שני צבעים **שונים בבירור** אחד מהשני (ומרקע המשחק, שהוא כחול-כהה) — אחרת יהיה קשה להבחין מי המחבט שלכם ומי של המחשב תוך כדי משחק.

---

## טבלת צבעים מוכנה להעתקה

כל הערכים האלה כבר בשימוש במקום אחר בפרויקט ובדוקים שעובדים על המסך:

| צבע | קוד להעתקה |
|---|---|
| אדום | `0xF800` |
| ירוק | `0x07E0` |
| כחול | `0x001F` |
| צהוב | `0xFFE0` |
| ורוד | `0xF81F` |
| כתום | `0xFD20` |
| טורקיז (ציאן) | `0x07FF` |
| לבן | `0xFFFF` |

---

## למי שרוצה להבין איך זה עובד (לא חובה)

הצבעים כתובים בפורמט שנקרא **RGB565** — מספר בן 16 סיביות (bit) שמייצג צבע ב-3 ערוצים: אדום (Red), ירוק (Green), כחול (Blue). השם "565" מגיע מכך שמוקצים 5 סיביות לאדום, 6 לירוק, ו-5 לכחול (יותר לירוק כי העין האנושית רגישה אליו יותר).

לדוגמה `0x07FF` (הצבע המקורי של מחבט השחקן): ב-בינארי זה `00000` `111111` `11111` — כלומר אדום=0 (כלום), ירוק=מלא, כחול=מלא → טורקיז.

**רוצים צבע מדויק משלכם ולא מהטבלה?** אפשר לחפש ברשת "RGB565 color picker" — כלים כאלה נותנים לכם לבחור צבע על גלגל צבעים ומחזירים את הקוד המתאים ב-hex, בדיוק בפורמט שהקוד כאן מצפה לו (`0xXXXX`).

---

## שלב 3 — קומפילציה, העלאה, ובדיקה

1. שמרו את הקובץ.
2. הריצו `pio run -e esp32s3` (לבדיקה כללית) או `pio run -e airhockey` (אם רוצים לבדוק רק את משחק הוקי האוויר העצמאי) — ובדקו שאין שגיאות קומפילציה.
3. אם הכול תקין: `pio run -e esp32s3 -t upload` (או `-e airhockey -t upload` למשחק העצמאי) כדי להעלות לבקר.
4. **בדיקה בפועל**: היכנסו ללשונית GAMES ← AIR HOCKEY, ותראו את שני המחבטים בצבעים החדשים שבחרתם.

---

## אתגר בונוס (לא חובה)

1. נסו לשנות גם את **`ColorPuck`** (צבע הדיסקית) או **`ColorBg`** (צבע הרקע) באותו האופן.
2. אתגר מתקדם יותר: מי שרוצה, יכול לנסות לגרום לצבע מחבט השחקן **להשתנות** כל פעם שהוא מקבל נקודה (רמז: תצטרכו למצוא איפה `_playerScore` מתעדכן בקובץ, ולהוסיף שם קוד ששולף צבע אחר ממערך צבעים בכל פעם).

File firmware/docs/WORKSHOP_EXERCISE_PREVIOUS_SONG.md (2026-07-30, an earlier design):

# תרגיל סדנה: הפיכת כפתור NEXT לכפתור "שיר קודם"

## המטרה

כרגע, לחיצה על הכפתור הפיזי המחובר ל-**GPIO45** (המסומן NEXT) מעבירה לשיר **הבא** ברשימה. במשימה הזו נשנה את ההתנהגות כך שאותו כפתור פיזי יעביר לשיר **הקודם** במקום.

לא נוגעים בחיווט או בחומרה — רק בקוד.

---

## רקע: איפה ההתנהגות הזו מוגדרת

שלושה קבצים מעורבים:

1. **`src/main.cpp`** — הקובץ הראשי שרץ כל הזמן בלולאה (`loop()`). הוא בודק אם הכפתור הפיזי נלחץ, ואם כן — קורא לפונקציה `jukeboxUI.nextSong()`.
2. **`src/JukeboxUI.h`** — קובץ ה-header, שם **מוצהר** (declared) אילו פונקציות קיימות במחלקה `JukeboxUI` — כולל הרשימה `void nextSong();`.
3. **`src/JukeboxUI.cpp`** — קובץ המימוש (implementation), שם באמת **כתוב** מה `nextSong()` עושה.

כדי שהכפתור יעביר לשיר קודם, נבצע 3 שינויים: נוסיף פונקציה חדשה `previousSong()` (הצהרה + מימוש), ואז נגרום ל-`main.cpp` לקרוא לה במקום ל-`nextSong()`.

---

## שלב 1 — הוספת הצהרה (declaration) ב-`src/JukeboxUI.h`

פתחו את `src/JukeboxUI.h`. מצאו את השורה (בערך שורה 15):

```cpp
void nextSong();
```

**הוסיפו מיד אחריה** שורה חדשה, כך שיהיה:

```cpp
void nextSong();
void previousSong();
```

---

## שלב 2 — הוספת המימוש (implementation) ב-`src/JukeboxUI.cpp`

פתחו את `src/JukeboxUI.cpp`. מצאו את הפונקציה (בערך שורה 507):

```cpp
void JukeboxUI::nextSong()
{
    if (songCount() > 0)
    {
        const int current = max(0, _songIndex);
        selectSong((current + 1) % songCount());
    }
}
```

**מיד אחריה** הוסיפו פונקציה חדשה, דומה כמעט לגמרי — רק **במקום `+ 1`** (קדימה) נשתמש ב-**`+ songCount() - 1`** (חזרה אחורה, עם "גלגול" לסוף הרשימה כשמגיעים להתחלה):

```cpp
void JukeboxUI::previousSong()
{
    if (songCount() > 0)
    {
        const int current = max(0, _songIndex);
        selectSong((current + songCount() - 1) % songCount());
    }
}
```

**למה `+ songCount() - 1` ולא סתם `- 1`?** כי ב-C++ אופרטור ה-`%` (שארית) לא מתנהג יפה עם מספרים שליליים. `(current - 1) % songCount()` יכול לצאת שלילי אם `current == 0`, מה שיגרום לקריסה של הגישה למערך. הטריק `+ songCount() - 1` מבטיח שהתוצאה תמיד חיובית, ועדיין נותן את אותה "תזוזה של שיר אחד אחורה, עם גלגול".

**טיפ:** זה בדיוק אותו החישוב שכבר קיים באותו קובץ, בפונקציה `handleTouch()`, בטיפול בכפתור "<<" (שיר קודם) שמופיע במסך ה-HOME על המסך המגע. אפשר לחפש בקובץ ולמצוא שורה כמעט זהה — זה סימן טוב שעשיתם את זה נכון.

---

## שלב 3 — שינוי `src/main.cpp` כדי לקרוא לפונקציה החדשה

פתחו את `src/main.cpp`. מצאו את הבלוק שמטפל בלחיצה על כפתור NEXT (בערך שורה 155–159):

```cpp
else if (pressed)
{
    Serial.println("[Button] NEXT pressed");
    jukeboxUI.nextSong();
}
```

שנו את השורה `jukeboxUI.nextSong();` ל:

```cpp
jukeboxUI.previousSong();
```

(אופציונלי: אפשר גם לשנות את טקסט ה-`Serial.println` כך שישקף את מה שבאמת קורה עכשיו — זה לא משפיע על ההתנהגות, רק על מה שמודפס ללוג).

---

## שלב 4 — קומפילציה, העלאה, ובדיקה

1. שמרו את כל שלושת הקבצים.
2. הריצו `pio run -e esp32s3` ובדקו שאין שגיאות קומפילציה.
3. אם הכול תקין: `pio run -e esp32s3 -t upload` כדי להעלות לבקר.
4. **בדיקה בפועל**: לחצו על כפתור NEXT הפיזי — הג'וקבוקס אמור לעבור ל**שיר הקודם** ברשימה, לא הבא.

---

## הערה חשובה

התרגיל הזה משנה **רק** את כפתור ה-NEXT (GPIO45). כפתור ה-PLAY/PAUSE (GPIO46) ממשיך לעבוד בדיוק כמו קודם — מפעיל/עוצר את השיר הנוכחי, בלי שינוי.

שימו לב גם: אם אתם משחקים בפינבול או בהוקי אוויר מלשונית ה-GAMES, שני הכפתורים האלה משמשים כרגע כפקדי משחק (פליפר / מחבט) ולא כ-NEXT/PLAY-PAUSE. השינוי שעשיתם משפיע רק על ההתנהגות **כשלא משחקים במשחק** — תוכלו לראות את זה בקובץ `main.cpp`, בתנאי `if (jukeboxUI.isPlayingGame())` שמסביב לקוד שהשתנה.

---

## אתגר בונוס (לא חובה)

למי שרוצה אתגר נוסף: אפשר לנסות לגרום לאותו כפתור פיזי להתנהג אחרת בהתאם לזמן הלחיצה — לחיצה קצרה = שיר הבא (ההתנהגות המקורית), לחיצה ארוכה (מוחזקת) = שיר קודם. (רמז: תצטרכו למדוד זמן לחיצה עם `millis()`, בדומה לאיך שכבר נעשה דיבאונס לכפתורים בקובץ `main.cpp`).

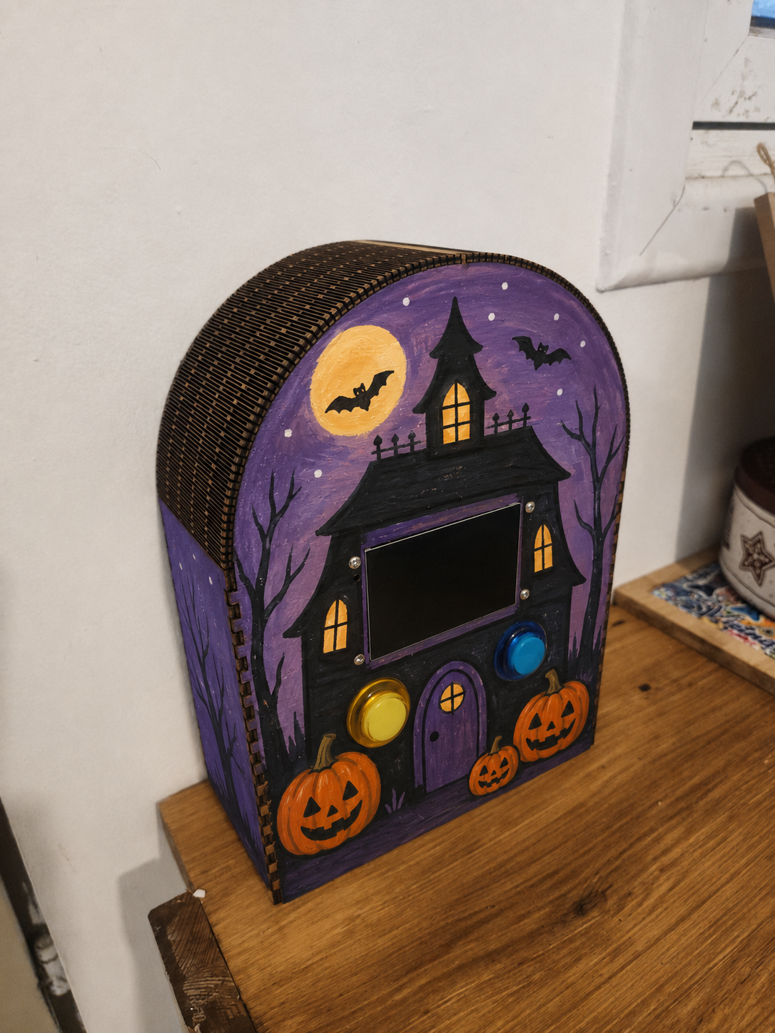
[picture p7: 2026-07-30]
design/8b6adec8-bf1c-4a5a-ae25-33abef92dfd1.png

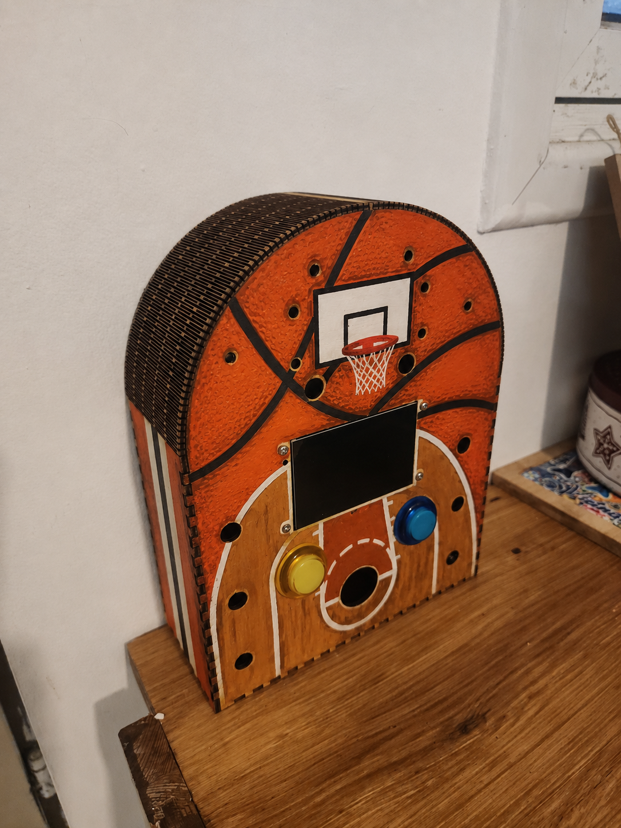
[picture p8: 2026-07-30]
design/ChatGPT Image Jul 11, 2026, 03_25_23 PM.png

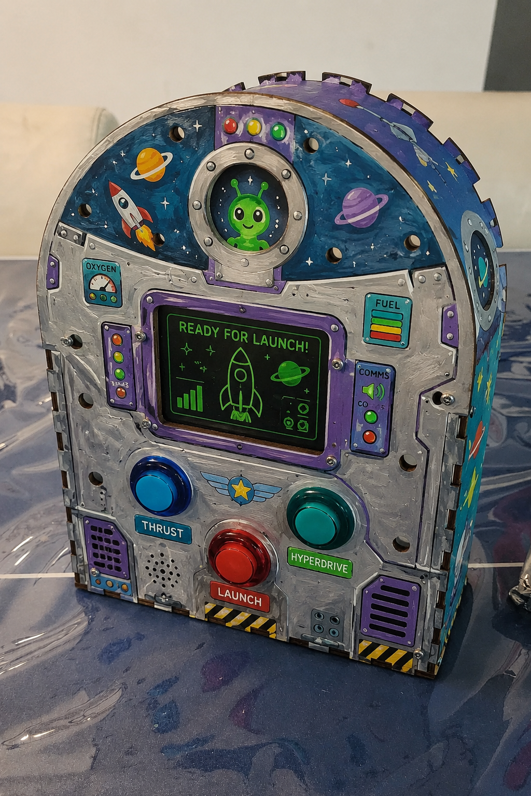
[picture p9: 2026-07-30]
design/ChatGPT Image Jul 7, 2026, 10_54_14 PM.png

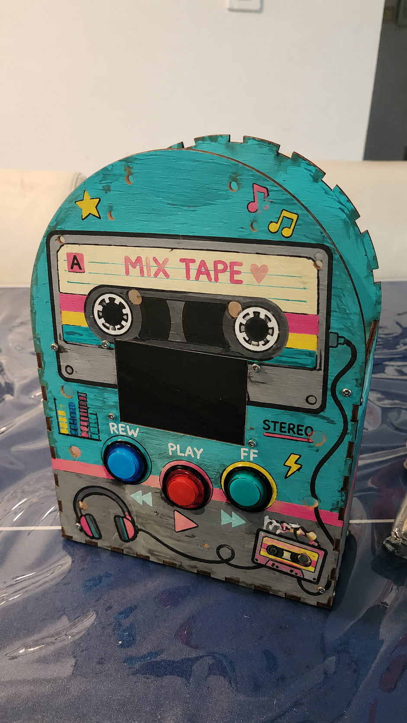
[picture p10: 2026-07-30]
design/ChatGPT Image Jul 7, 2026, 11_00_27 PM.png

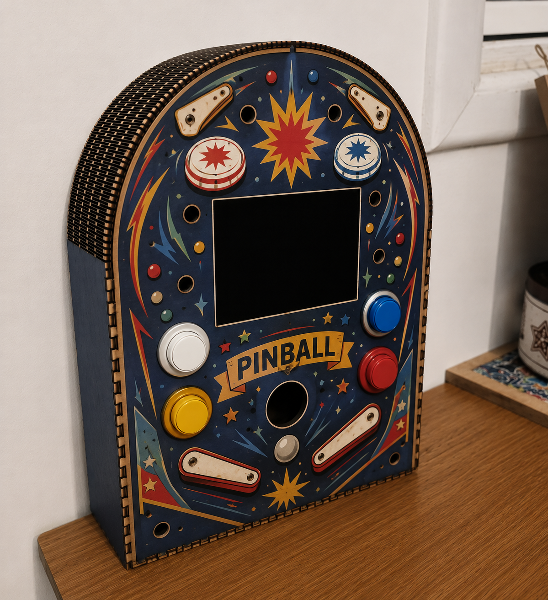
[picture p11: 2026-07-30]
design/d52ac31c-1df0-4437-a37b-5f325060ff30.png

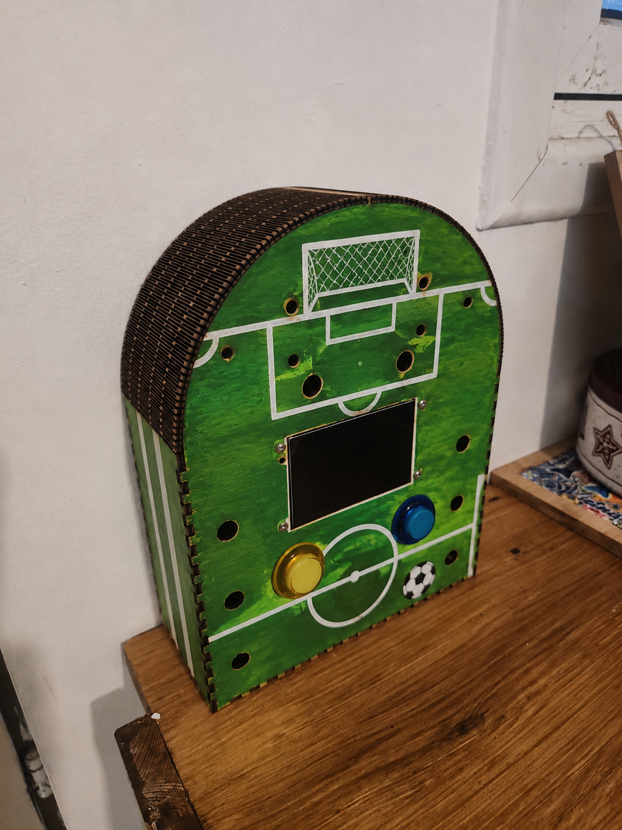
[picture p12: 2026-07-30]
design/ChatGPT Image Jul 11, 2026, 03_27_18 PM.png

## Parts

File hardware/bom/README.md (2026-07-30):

# Bill of Materials

- [`COMPONENTS.md`](COMPONENTS.md) — plain-text/Markdown version of the BOM, readable directly on GitHub, no spreadsheet app needed.
- [`ESP32_Jukebox_BOM_English_Open_Source.xlsx`](ESP32_Jukebox_BOM_English_Open_Source.xlsx) — the English spreadsheet `COMPONENTS.md` was generated from.
- [`ESP32_Jukebox_BOM_AliExpress_Prices_3105.xlsx`](ESP32_Jukebox_BOM_AliExpress_Prices_3105.xlsx) — original Hebrew working spreadsheet (workshop-quantity multiplier, price-sourcing notes).

Full component list for building a Juckbox, with quantities, specs, and per-unit prices. See the **Notes** sheet inside either spreadsheet for how to use it (link types, adjusting workshop quantity, price sourcing).

Most links currently point to an AliExpress search for the part (so you can pick a seller by stock, shipping, and rating) rather than one specific listing — the exception is the ESP32 display board, which links directly to the supplied listing.

## Affiliate Disclosure

Some links in this BOM may be AliExpress affiliate links, marked **Affiliate** in the sheet once added. If you purchase through a marked link, the project maintainer may receive a small commission at no additional cost to you — this never affects which component is recommended, and using the link is entirely optional. Every row also lists the part's name and search specification, so you can always look it up independently instead.

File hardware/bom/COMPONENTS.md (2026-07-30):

# Component List

Plain-text version of the [BOM spreadsheet](ESP32_Jukebox_BOM_English_Open_Source.xlsx) for quick reference on GitHub — quantities are **per single Juckbox build**. The spreadsheet also has a workshop-batch multiplier and a Notes sheet with more detail.

See the [Affiliate Disclosure](README.md#affiliate-disclosure) above before buying through any of these links.

## Required components

| Component | Spec / model | Qty | Unit price (ILS) | Link | Notes |
|---|---|---|---|---|---|
| ESP32 board with 2.8-inch TFT display | ESP32 development board with 2.8 inch TFT touch screen, WiFi, Bluetooth | 1 | ₪66 | [Buy](https://he.aliexpress.com/item/1005012332770886.html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) | Main system board. Use the provided link. |
| microSD card | microSD card 8GB or 16GB, Class 10 | 1 | ₪12 | [Buy](https://he.aliexpress.com/item/1005012379392487.html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) | For storing MP3 files. Format the card according to DFPlayer requirements. |
| Blue push button x25 | Arcade push button momentary 24mm or 30mm, NO contact | 1 | ₪5 | [Buy](https://he.aliexpress.com/item/1005003514180571.html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) | Basic quantity for a jukebox with Play, Next, Previous, Volume, Select, and selection buttons. |
| Red push button x25 | Arcade push button momentary 24mm or 30mm, NO contact | 1 | ₪5 | [Buy](https://he.aliexpress.com/item/1005003514180571.html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) | Basic quantity for a jukebox with Play, Next, Previous, Volume, Select, and selection buttons. |
| White push button x25 | Arcade push button momentary 24mm or 30mm, NO contact | 1 | ₪5 | [Buy](https://he.aliexpress.com/item/1005003514180571.html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) | Basic quantity for a jukebox with Play, Next, Previous, Volume, Select, and selection buttons. |
| Heat-shrink tubing (assorted kit) |  | 1 kit for the whole build | — | [Buy](https://he.aliexpress.com/item/1005011926896084.html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) | For soldering joints/wire splices. |
| 1 kOhm resistors |  | — | — | search locally / hardware store |  |
| White Glue |  | — | — | search locally / hardware store |  |
| Instant Glue |  | — | — | search locally / hardware store |  |
| Double-Sided Tape |  | — | — | search locally / hardware store |  |
| M3 x 10 mm Screws |  | 4 | — | search locally / hardware store |  |

## Optional components

| Component | Spec / model | Qty | Unit price (ILS) | Link | Notes |
|---|---|---|---|---|---|
| Solderable Perfboard | Prototype PCB perfboard, 5x7cm or similar | 1 | — | [Buy](https://he.aliexpress.com/item/1005008733140767.html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) | For a permanent and clean installation inside the enclosure. |
| MCP23017 I2C GPIO Expander | MCP23017 16-bit I2C I/O expander module | 1 | ₪6.68 | [Buy](https://he.aliexpress.com/item/1005009520862205.html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) | Connects most of the buttons without using up the display board's GPIO pins. |
| Green push button x25 | Arcade push button momentary 24mm or 30mm, NO contact | 1 | ₪5 | [Buy](https://he.aliexpress.com/item/1005003514180571.html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) | Basic quantity for a jukebox with Play, Next, Previous, Volume, Select, and selection buttons. |
| Yellow push button x25 | Arcade push button momentary 24mm or 30mm, NO contact | 1 | ₪5 | [Buy](https://he.aliexpress.com/item/1005003514180571.html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) | Basic quantity for a jukebox with Play, Next, Previous, Volume, Select, and selection buttons. |
| PAM8403 Amplifier | PAM8403 5V class D stereo amplifier board, 2x3W | 1 | ₪12.99 | [Buy](https://he.aliexpress.com/item/1005011851498125.html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) | Simple amplifier for small speakers. Receives the audio signal from the DFPlayer. |
| Speakers | 4 ohm 3W or 5W speakers, 40mm to 60mm | 2 | ₪6.45 | [Buy](https://he.aliexpress.com/item/1005007851136722.html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) | Match the speakers to the size of the speaker grille in the enclosure. |
| Main Power Switch | Panel mount rocker switch, 2 pin, 5V/12V compatible | 1 | — | [Buy](https://he.aliexpress.com/item/1005006303104334.html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) | Turns the entire system on and off. |
| Dupont / JST Wires | Dupont wires and JST connectors kit | 1 | — | [Buy](https://he.aliexpress.com/w/wholesale-Dupont-wire-JST-connector-kit.html) | For connecting modules, buttons, and lighting. |

## Notes

- Most links point to an AliExpress **search** for the part rather than one fixed listing, so you can pick a seller by stock, shipping, and rating. The ESP32 display board links to the specific listing that was used and verified.
- Prices are per-unit in ILS (₪), captured 2026-05-31, and will drift — always confirm the current price before ordering.
- Mechanical parts (laser-cut enclosure panels, 3D-printed decorations, screws, glue, tape) are not sold as a kit — see [hardware/enclosure/](../enclosure) for the cut files and source them locally.

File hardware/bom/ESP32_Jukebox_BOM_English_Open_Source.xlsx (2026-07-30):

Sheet: BOM_Electronics
Electronic Components BOM - ESP32 Jukebox with Display
Number of workshop kits | 20 |  | Created on | 2026-05-30 |  | Note | The links are AliExpress search links, except for the ESP32 board, where the provided link was used.
No. | Status | Subsystem | Component | Search Specification / Model | Qty per Unit | Qty for Workshop | Link Type | AliExpress Search Link | AliExpress Item Link | Unit Price (ILS) | Notes | Price Source | Price Note | Checked On | Estimated Cost per Project | Estimated Cost for Workshop
1 | Required | Control and Interface | ESP32 board with 2.8-inch TFT display | ESP32 development board with 2.8 inch TFT touch screen, WiFi, Bluetooth | 1 | 20 | Specific Product |  | XiaoZhi AI 3.5inch 320*480 Smart Display Screen Touch Enabled LED TFT Module | 66.00 | Main system board. Use the provided link. |  | Price based on the screenshot supplied by the user. | 2026-05-31 | 66.00 | 1320.00
3 | Required | Storage | microSD card | microSD card 8GB or 16GB, Class 10 | 1 | 20 | Search | microSD card (https://he.aliexpress.com/item/1005012379392487.html) | microSD card 8GB or 16GB, Class 10 | 12.00 | For storing MP3 files. Format the card according to DFPlayer requirements. | https://he.pricearchive.org/search/aliexpress.com/16-gb-micro-sd-tf-card/2?sort=SALE_PRICE_ASC | Price found in an external AliExpress price-tracking source. | 2026-05-31 | 12.00 | 240.00
5 | Required | Buttons | Blue push button x25 | Arcade push button momentary 24mm or 30mm, NO contact | 1 | 20 | Search | Blue push button x25 (https://he.aliexpress.com/w/wholesale-arcade-push-button-momentary-24mm-30mm.html) | https://he.aliexpress.com/item/1005003514180571.html | 5.00 | Basic quantity for a jukebox with Play, Next, Previous, Volume, Select, and selection buttons. | https://ms.pricearchive.org/aliexpress.com/item/32709040184 | Unit price calculated from a 10-piece pack. | 2026-05-31 | 5.00 | 100.00
5 | Required | Buttons | Red push button x25 | Arcade push button momentary 24mm or 30mm, NO contact | 1 | 20 | Search | Red push button x25 | Arcade push button momentary 24mm or 30mm, NO contact | 5.00 | Basic quantity for a jukebox with Play, Next, Previous, Volume, Select, and selection buttons. | https://ms.pricearchive.org/aliexpress.com/item/32709040184 | Unit price calculated from a 10-piece pack. | 2026-05-31 | 5.00 | 100.00
5 | Required | Buttons | White push button x25 | Arcade push button momentary 24mm or 30mm, NO contact | 1 | 20 | Search | White push button x25 | Arcade push button momentary 24mm or 30mm, NO contact | 5.00 | Basic quantity for a jukebox with Play, Next, Previous, Volume, Select, and selection buttons. | https://ms.pricearchive.org/aliexpress.com/item/32709040184 | Unit price calculated from a 10-piece pack. | 2026-05-31 | 5.00 | 100.00
 | Required | Heat-Shrink Tubing | Workshop kit |  |  | 1 |  |  | https://he.aliexpress.com/item/1005011926896084.html
 | Required | Resistors | 1 kOhm resistors
 | Required | White Glue
 | Required | Instant Glue
 | Required | Double-Sided Tape
 | Required | M3 x 10 mm Screws |  |  | 4 | 100
16 | Optional | Assembly | Solderable Perfboard | Prototype PCB perfboard, 5x7cm or similar | 1 | 20 | Search | Solderable Perfboard | https://he.aliexpress.com/item/1005008733140767.html?scm_id=1007.40050.354490.0&scm-url=1007.40050.354490.0 |  | For a permanent and clean installation inside the enclosure.
4 | Optional | Input Expansion | MCP23017 I2C GPIO Expander | MCP23017 16-bit I2C I/O expander module | 1 | 20 | Search | https://he.aliexpress.com/w/wholesale-MCP23017-I2C-GPIO-expander-module.html | https://he.aliexpress.com/item/1005009520862205.html?sk=_c3dLGmFL | 6.68 | Connects most of the buttons without using up the display board's GPIO pins. | https://cs.pricearchive.org/aliexpress.com/item/1005009520862205 | Price found in an external AliExpress price-tracking source. | 2026-05-31 | 6.68 | 133.60
5 | Optional | Buttons | Green push button x25 | Arcade push button momentary 24mm or 30mm, NO contact | 1 | 20 | Search | Green push button x25 (https://he.aliexpress.com/w/wholesale-arcade-push-button-momentary-24mm-30mm.html) | https://he.aliexpress.com/item/1005003514180571.html | 5.00 | Basic quantity for a jukebox with Play, Next, Previous, Volume, Select, and selection buttons. | https://ms.pricearchive.org/aliexpress.com/item/32709040184 | Unit price calculated from a 10-piece pack. | 2026-05-31 | 5.00 | 100.00
5 | Optional | Buttons | Yellow push button x25 | Arcade push button momentary 24mm or 30mm, NO contact | 1 | 20 | Search | Yellow push button x25 | Arcade push button momentary 24mm or 30mm, NO contact | 5.00 | Basic quantity for a jukebox with Play, Next, Previous, Volume, Select, and selection buttons. | https://ms.pricearchive.org/aliexpress.com/item/32709040184 | Unit price calculated from a 10-piece pack. | 2026-05-31 | 5.00 | 100.00
6 | Optional | Audio | PAM8403 Amplifier | PAM8403 5V class D stereo amplifier board, 2x3W | 1 | 20 | Search | PAM8403 Amplifier | https://he.aliexpress.com/item/1005011851498125.html | 12.99 | Simple amplifier for small speakers. Receives the audio signal from the DFPlayer. | https://www.pricearchive.org/aliexpress.com/item/1005012082823079 | Price found in an external AliExpress price-tracking source. | 2026-05-31 | 12.99 | 259.80
7 | Optional | Audio | Speakers | 4 ohm 3W or 5W speakers, 40mm to 60mm | 2 | 40 | Search | Speakers | https://he.aliexpress.com/item/1005007851136722.html | 6.45 | Match the speakers to the size of the speaker grille in the enclosure. | https://he.pricearchive.org/search/aliexpress.com/3-ohm-speaker/1 | Price found in an external AliExpress price-tracking source. | 2026-05-31 | 12.90 | 258.00
11 | Optional | Power | Main Power Switch | Panel mount rocker switch, 2 pin, 5V/12V compatible | 1 | 20 | Search | Main Power Switch | https://he.aliexpress.com/item/1005006303104334.html |  | Turns the entire system on and off.
13 | Optional | Wiring | Dupont / JST Wires | Dupont wires and JST connectors kit | 1 | 20 | Search | Dupont / JST Wires (https://he.aliexpress.com/w/wholesale-Dupont-wire-JST-connector-kit.html) | Dupont wires and JST connectors kit |  | For connecting modules, buttons, and lighting.
Partial price summary for components with available prices |  |  |  |  |  |  |  |  |  | 129.12 | Components with prices |  |  |  | 135.57 | 2711.40
Components without prices were left blank because no sufficiently clear price source was found on AliExpress or in a price tracker.

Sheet: Sheet1
The laser-cut file is located in the folder | 4 mm poplar plywood
M3 screws, 10 mm long | 8 per kit
Soldering stations

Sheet: Notes
BOM Usage Instructions
Topic | Details
Link Types | The links in the BOM sheet are clickable. Each cell displays the component name instead of a long URL. Most components link to an AliExpress search so a seller can be selected based on stock, shipping, and rating.
Prices | The unit price column is left blank for manual completion after selecting a seller, because AliExpress prices and shipping costs change frequently.
Workshop Quantity | Change cell B2 in the BOM_Electronics sheet to the desired number of kits. The workshop quantity column is calculated automatically.
Working Version | This BOM is intended for the version without a Raspberry Pi: ESP32 with display, DFPlayer Mini, amplifier, speakers, buttons, and lighting.
Mechanical Parts | The laser-cut enclosure and the PLA-printed decorations are not included because this BOM focuses on electronic components.
Price Updates | Prices were entered only when a sufficiently clear price source was found. Components without a clear source were left without a price.
Sources | Price sources are listed in the Price Source column of the BOM_Electronics sheet.
Board Price | The ESP32 board price was taken from the screenshot and link supplied by the user.
Price Accuracy | AliExpress prices vary by shipping, coupons, currency, quantity, and destination country. Verify all prices before placing an order.

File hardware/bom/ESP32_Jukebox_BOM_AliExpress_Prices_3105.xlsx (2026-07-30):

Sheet: BOM_Electronics
BOM רכיבים אלקטרוניים - ג׳וקבוקס ESP32 עם מסך
מספר ערכות בסדנה | 20 |  | תאריך יצירה | 2026-05-30 |  | הערה | הקישורים הם קישורי AliExpress לחיפוש, למעט לוח ה-ESP32 שבו הוכנס הקישור שסופק.
מס׳ | סטטוס | תת מערכת | רכיב | מפרט לחיפוש / דגם | כמות ליחידה | כמות לסדנה | סוג קישור | קישור AliExpress חיפוש | קישור AliExpress פריט | מחיר יחידה בשח | הערות | מקור מחיר | הערת מחיר | תאריך בדיקה | עלות משוערת לפרויקט | עלות משוערת לסדנה
1 | חובה | בקרה וממשק | לוח ESP32 עם מסך TFT 2.8 אינץ׳ | ESP32 development board with 2.8 inch TFT touch screen, WiFi, Bluetooth | 1 | 20 | מוצר ספציפי |  | XiaoZhi AI 3.5inch 320*480 Smart Display Screen Touch Enabled LED TFT Module (https://he.aliexpress.com/item/1005012332770886.html) | 66.00 | הלוח המרכזי של המערכת. להשתמש בקישור שסופק. |  | מחיר לפי צילום המסך שסופק על ידי המשתמש. | 2026-05-31 | 66.00 | 1320.00
3 | חובה | אחסון | כרטיס microSD | microSD card 8GB or 16GB, Class 10 | 1 | 20 | חיפוש | כרטיס microSD (https://he.aliexpress.com/item/1005012379392487.html) | microSD card 8GB or 16GB, Class 10 | 12.00 | לשמירת קובצי MP3. יש לפרמט לפי דרישות DFPlayer. | https://he.pricearchive.org/search/aliexpress.com/16-gb-micro-sd-tf-card/2?sort=SALE_PRICE_ASC | מחיר נמצא במקור חיצוני למעקב מחירי AliExpress. | 2026-05-31 | 12.00 | 240.00
5 | חובה | כפתורים | כפתור כחול X 25 | Arcade push button momentary 24mm or 30mm, NO contact | 1 | 20 | חיפוש | כפתור כחול X 25 (https://he.aliexpress.com/w/wholesale-arcade-push-button-momentary-24mm-30mm.html) | Arcade push button momentary 24mm or 30mm, NO contact (https://he.aliexpress.com/item/1005003514180571.html) | 5.00 | כמות בסיסית לג׳וקבוקס עם Play, Next, Prev, Volume, Select וכפתורי בחירה. | https://ms.pricearchive.org/aliexpress.com/item/32709040184 | מחיר מחושב ליחידה מתוך מארז 10 יחידות. | 2026-05-31 | 5.00 | 100.00
5 | חובה | כפתורים | כפתור אדום X 25 | Arcade push button momentary 24mm or 30mm, NO contact | 1 | 20 | חיפוש | כפתור אדום X 25 | Arcade push button momentary 24mm or 30mm, NO contact | 5.00 | כמות בסיסית לג׳וקבוקס עם Play, Next, Prev, Volume, Select וכפתורי בחירה. | https://ms.pricearchive.org/aliexpress.com/item/32709040184 | מחיר מחושב ליחידה מתוך מארז 10 יחידות. | 2026-05-31 | 5.00 | 100.00
5 | חובה | כפתורים | כפתור לבן X 25 | Arcade push button momentary 24mm or 30mm, NO contact | 1 | 20 | חיפוש | כפתור לבן X 25 | Arcade push button momentary 24mm or 30mm, NO contact | 5.00 | כמות בסיסית לג׳וקבוקס עם Play, Next, Prev, Volume, Select וכפתורי בחירה. | https://ms.pricearchive.org/aliexpress.com/item/32709040184 | מחיר מחושב ליחידה מתוך מארז 10 יחידות. | 2026-05-31 | 5.00 | 100.00
 | חובה | שרינקים להלחמה | קיט לכל הסדנה |  |  | 1 |  |  | https://he.aliexpress.com/item/1005011926896084.html?curPageLogUid=MYg3zF1CkI8u
 | חובה | נגדים | נגדי 1K OM
 | חובה | דבק לבן
 | חובה | דבק מהיר
 | חובה | דבק דו צדדי
 | חובה | ברגי M3 X 10 |  |  | 4 | 100
16 | אופציונלי | הרכבה | לוח הלחמה / פרוטובורד | Prototype PCB perfboard, 5x7cm or similar | 1 | 20 | חיפוש | לוח הלחמה / פרוטובורד (https://he.aliexpress.com/w/wholesale-prototype-PCB-perfboard-5x7cm.html) | Prototype PCB perfboard, 5x7cm or similar (https://he.aliexpress.com/item/1005008733140767.html?scm_id=1007.40050.354490.0&scm-url=1007.40050.354490.0) |  | להרכבה קבועה ונקייה בתוך המארז.
4 | אופציונלי | הרחבת כניסות | MCP23017 I2C GPIO Expander | MCP23017 16-bit I2C I/O expander module | 1 | 20 | חיפוש | MCP23017 I2C GPIO Expander (https://he.aliexpress.com/w/wholesale-MCP23017-I2C-GPIO-expander-module.html) | MCP23017 16-bit I2C I/O expander module (https://he.aliexpress.com/item/1005009520862205.html?sk=_c3dLGmFL) | 6.68 | לחיבור רוב הכפתורים בלי לבזבז GPIO של המסך. | https://cs.pricearchive.org/aliexpress.com/item/1005009520862205 | מחיר נמצא במקור חיצוני למעקב מחירי AliExpress. | 2026-05-31 | 6.68 | 133.60
5 | אופציונלי | כפתורים | כפתור ירוק X25 | Arcade push button momentary 24mm or 30mm, NO contact | 1 | 20 | חיפוש | כפתור ירוק X25 (https://he.aliexpress.com/w/wholesale-arcade-push-button-momentary-24mm-30mm.html) | Arcade push button momentary 24mm or 30mm, NO contact (https://he.aliexpress.com/item/1005003514180571.html) | 5.00 | כמות בסיסית לג׳וקבוקס עם Play, Next, Prev, Volume, Select וכפתורי בחירה. | https://ms.pricearchive.org/aliexpress.com/item/32709040184 | מחיר מחושב ליחידה מתוך מארז 10 יחידות. | 2026-05-31 | 5.00 | 100.00
5 | אופציונלי | כפתורים | כפתור צהובX 25 | Arcade push button momentary 24mm or 30mm, NO contact | 1 | 20 | חיפוש | כפתור צהובX 25 | Arcade push button momentary 24mm or 30mm, NO contact | 5.00 | כמות בסיסית לג׳וקבוקס עם Play, Next, Prev, Volume, Select וכפתורי בחירה. | https://ms.pricearchive.org/aliexpress.com/item/32709040184 | מחיר מחושב ליחידה מתוך מארז 10 יחידות. | 2026-05-31 | 5.00 | 100.00
6 | אופציונלי | אודיו | מגבר PAM8403 | PAM8403 5V class D stereo amplifier board, 2x3W | 1 | 20 | חיפוש | מגבר PAM8403 (https://he.aliexpress.com/w/wholesale-PAM8403-5V-2x3W-amplifier-board.html) | PAM8403 5V class D stereo amplifier board, 2x3W (https://he.aliexpress.com/item/1005011851498125.html) | 12.99 | מגבר פשוט לרמקולים קטנים. מקבל אות אודיו מה-DFPlayer. | https://www.pricearchive.org/aliexpress.com/item/1005012082823079 | מחיר נמצא במקור חיצוני למעקב מחירי AliExpress. | 2026-05-31 | 12.99 | 259.80
7 | אופציונלי | אודיו | רמקולים | 4 ohm 3W or 5W speakers, 40mm to 60mm | 2 | 40 | חיפוש | רמקולים (https://he.aliexpress.com/w/wholesale-4-ohm-3W-speaker-50mm.html) | 4 ohm 3W or 5W speakers, 40mm to 60mm (https://he.aliexpress.com/item/1005007851136722.html) | 6.45 | להתאים לגודל גריל הרמקול במארז. | https://he.pricearchive.org/search/aliexpress.com/3-ohm-speaker/1 | מחיר נמצא במקור חיצוני למעקב מחירי AliExpress. | 2026-05-31 | 12.90 | 258.00
11 | אופציונלי | הספק | מפסק ראשי | Panel mount rocker switch, 2 pin, 5V/12V compatible | 1 | 20 | חיפוש | מפסק ראשי (https://he.aliexpress.com/w/wholesale-panel-mount-rocker-switch-2-pin.html) | Panel mount rocker switch, 2 pin, 5V/12V compatible (https://he.aliexpress.com/item/1005006303104334.html) |  | הפעלה וכיבוי של כל המערכת. |  |  |  | #VALUE! | #VALUE!
13 | אופציונלי | חיווט | חוטי Dupont / JST | Dupont wires and JST connectors kit | 1 | 20 | חיפוש | חוטי Dupont / JST (https://he.aliexpress.com/w/wholesale-Dupont-wire-JST-connector-kit.html) | Dupont wires and JST connectors kit |  | לחיבור מודולים, כפתורים ותאורה. |  |  |  | #VALUE! | #VALUE!
סיכום מחירים חלקי לפי הרכיבים שנמצאו |  |  |  |  |  |  |  |  |  | 129.12 | רכיבים עם מחיר |  |  |  | #VALUE! | #VALUE!
רכיבים ללא מחיר נשארו ריקים כי לא נמצא מקור מחיר ברור מספיק באלי אקספרס או במעקב מחירים.

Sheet: Sheet1
קובץ לחיתוך נמצא בתיקייה | 4 מ"מ צפצפה
ברגי 3m אורך 10 | 8 לערכה
עמדות הלחמה

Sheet: Notes
הנחיות שימוש ב-BOM
נושא | פירוט
סוג הקישורים | הקישורים בגיליון ה-BOM הם קישורים לחיצים. התא מציג את שם הרכיב במקום URL ארוך. רוב הרכיבים מפנים לחיפוש ב-AliExpress כדי לבחור מוכר לפי מלאי, משלוח ודירוג.
מחירים | עמודת מחיר יחידה נשארה ריקה למילוי ידני לאחר בחירת מוכר, כי מחירי AliExpress ומשלוחים משתנים.
כמות לסדנה | שנה את התא B2 בגיליון BOM_Electronics למספר הערכות הרצוי. עמודת כמות לסדנה תחושב אוטומטית.
גרסת עבודה | ה-BOM מכוון לגרסה ללא Raspberry Pi: ESP32 עם מסך, DFPlayer Mini, מגבר, רמקולים, כפתורים ותאורה.
מכניקה | המארז החתוך בלייזר והעיטורים המודפסים מ-PLA לא נכללים כאן כי הבקשה היא לרכיבים אלקטרוניים.
עדכון מחירים | מחירים מולאו רק כאשר נמצא מקור מחיר ברור מספיק. רכיבים שלא נמצא להם מקור ברור נשארו ללא מחיר.
מקורות | מקורות המחיר מופיעים בעמודת מקור מחיר בגיליון BOM_Electronics.
מחיר הלוח | מחיר לוח ה-ESP32 נלקח מהצילום שסופק על ידי המשתמש ומהקישור שסופק.
דיוק מחירים | מחירי AliExpress משתנים לפי משלוח, קופונים, מטבע, כמות ומדינה. יש לאמת לפני הזמנה בפועל.

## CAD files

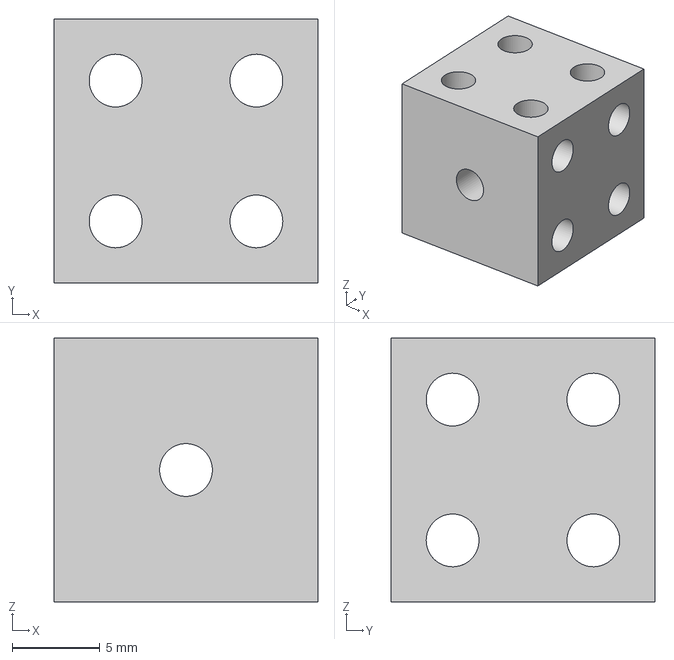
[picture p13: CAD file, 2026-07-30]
hardware/enclosure/Cube.step
15.0 x 15.0 x 15.0 mm

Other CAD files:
hardware/enclosure/Cube.stl

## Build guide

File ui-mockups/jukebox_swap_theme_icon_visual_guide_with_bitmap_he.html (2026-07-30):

🎨 תרגיל סדנה - ערכות נושא ואייקונים

# החלפת אייקון לערכת נושא קיימת

נבחר ערכת נושא אחת ונחליף את האייקון שלה באייקון שכבר קיים בפרויקט. לא משנים את צבעי הערכה או את השם שלה - רק את האייקון שמופיע במסך HOME.

2 שלבים קובץ אחד 10 אייקונים לבחירה ללא שינוי בחומרה

🎯

## המטרה

לג'וקבוקס יש 10 ערכות נושא. כל ערכה מציגה אייקון קטן בגודל 16x16 פיקסלים בשוליים של מסך HOME. בתרגיל נחליף לערכה אחת את האייקון שלה באייקון של ערכה אחרת.

1. בחירת שורה ואייקון 2. קומפילציה והעלאה

📁

## איפה משנים?

src/JukeboxUI.cpp

הקובץ היחיד שבו צריך לבצע שינוי.

drawThemeDecorations()

הפונקציה שמחליטה איזה אייקון יקבל כל Theme.

switch (themeManager.current())

טבלת ההתאמה בין ערכת הנושא לבין האייקון שלה.

🔗

## טבלת ההתאמה הקיימת

כל שורת case מחברת ערכת נושא לאייקון. אין צורך ליצור אייקון חדש - מספיק להחליף את השם שמופיע אחרי סימן השוויון.

הקוד הקיים בקובץ בערך בשורות 1009-1022

const uint8_t* icon = nullptr;
switch (themeManager.current())
{
    case THEME_PINEAPPLE: icon = iconPineapple; break;
    case THEME_RETRO_ARCADE: icon = iconStar; break;
    case THEME_ROBOT: icon = iconRobot; break;
    case THEME_SPACESHIP: icon = iconSpaceship; break;
    case THEME_PIRATE: icon = iconSkull; break;
    case THEME_VINTAGE_RADIO: icon = iconSpeaker; break;
    case THEME_CASSETTE: icon = iconCassette; break;
    case THEME_FOREST: icon = iconTree; break;
    case THEME_STEAMPUNK: icon = iconGear; break;
    case THEME_MONSTER: icon = iconMonster; break;
    default: break;  // Classic, Custom: no icon
}

🧩

#### איך קוראים את השורה?

לדוגמה, השורה של Pineapple אומרת: כאשר ערכת הנושא הנוכחית היא THEME_PINEAPPLE, השתמשו באייקון iconPineapple.

🖼️

## האייקונים שכבר קיימים בפרויקט

אפשר לבחור כל אחד מעשרת האייקונים ולהצמיד אותו לכל ערכת נושא.

🍍

אננס

iconPineapple

⭐

כוכב

iconStar

🤖

רובוט

iconRobot

🚀

חללית

iconSpaceship

☠️

גולגולת

iconSkull

🔊

רמקול

iconSpeaker

📼

קלטת

iconCassette

🌲

עץ

iconTree

⚙️

גלגל שיניים

iconGear

👾

מפלצת

iconMonster

💡

#### שימו לב

האימוג'ים בכרטיסים הם המחשה בלבד. במסך הג'וקבוקס יוצג אייקון הפיקסלים האמיתי בגודל 16x16 שמוגדר בקוד.

## שלבי העבודה

שנו רק את שם האייקון שאחרי סימן השוויון

1

### בחרו ערכת נושא ואייקון חדש

src/JukeboxUI.cpp

מצאו את בלוק ה-switch ובחרו שורה אחת לשינוי. בדוגמה הזו נחליף את האייקון של Pineapple מאננס לגולגולת.

לפני

case THEME_PINEAPPLE: icon = iconPineapple; break;

אחרי

case THEME_PINEAPPLE: icon = iconSkull; break;

⚠️

#### מה בדיוק משנים?

משנים רק את החלק שמופיע אחרי icon =. אל תשנו את case THEME_PINEAPPLE, את המילה break או את הנקודה-פסיק בסוף.

🎲

#### אפשר לבחור כל צירוף

כל ערכת נושא יכולה לקבל כל אחד מעשרת האייקונים, גם כאשר האייקון שייך במקור לערכה אחרת.

2

### קומפילציה, העלאה ובדיקה

PlatformIO / ESP32-S3

✓

שמרו את הקובץ src/JukeboxUI.cpp.

✓

הריצו קומפילציה ובדקו שאין שגיאות: pio run -e esp32s3

✓

אם הכול תקין, העלו את הקוד לבקר: pio run -e esp32s3 -t upload

✓

במסך HOME פתחו SETTINGS ← THEME, בחרו את הערכה ששיניתם ובדקו שהאייקון החדש מופיע בשוליים השמאליים והימניים של המסך.

📌

## מה לא משתנה בתרגיל?

צבעי ערכת הנושא, השם שלה ושאר ההתנהגות נשארים כפי שהיו. השינוי משפיע רק על ציור האייקון הקטן שמופיע בעיצוב מסך HOME.

בערכות Classic ו-Custom לא מופיע אייקון, מפני שהן מגיעות אל שורת default שבה הערך נשאר nullptr.

🧱

## איך האייקונים מצוירים בקוד?

כל אייקון הוא תמונת Bitmap קטנה בגודל 16x16 פיקסלים. הקוד אינו שומר תמונה רגילה, אלא רשימה של ביטים: 1 מסמן פיקסל שמצויר ו-0 מסמן פיקסל שנשאר כבוי.

16שורות באייקון

16פיקסלים בכל שורה

2 bytesלכל שורה

32 bytesלאייקון שלם

🎨

#### המערך שומר צורה, לא צבע

ערכי ה-0 וה-1 קובעים רק איפה לצייר. הצבע של האייקון נבחר במקום אחר בקוד בהתאם לצבע ערכת הנושא.

### תצוגה של iconPineapple

כל ריבוע ירוק מייצג ביט שערכו 1.

#### כל זוג מספרים מייצג שורה אחת

לדוגמה, הזוג 0x07, 0xE0 מייצג 16 ביטים:

0000 0111 1110 0000

ששת הביטים הדולקים במרכז הופכים לשישה פיקסלים מצוירים בשורה.

#### דוגמה נוספת: 0x01, 0x80

בבינארי מתקבל 00000001 10000000, ולכן מופיעים שני פיקסלים במרכז:

#### למה שני בתים?

טיפוס הנתונים uint8_t מחזיק 8 ביטים בלבד. שורה באייקון מכילה 16 פיקסלים, לכן צריך שני ערכים: הבית הראשון עבור שמונת הפיקסלים הראשונים והבית השני עבור שמונת הפיקסלים הבאים.

המערך של אייקון האננס 16 זוגות של ערכי Hex

static const uint8_t iconPineapple[] = {
    0x00, 0x00,
    0x01, 0x80,
    0x01, 0x80,
    0x03, 0xC0,
    0x03, 0xC0,
    0x06, 0x60,
    0x00, 0x00,
    0x07, 0xE0,
    0x0F, 0xF0,
    0x0F, 0xF0,
    0x1F, 0xF8,
    0x1F, 0xF8,
    0x0F, 0xF0,
    0x0F, 0xF0,
    0x07, 0xE0,
    0x00, 0x00
};

💡

#### איך קוראים Hex?

כל ספרה הקסדצימלית מייצגת 4 ביטים. לדוגמה: 0x0F = 00001111, 0xF0 = 11110000, 0xFF = 11111111.

### מה אומרת ההגדרה?

static

האייקון זמין בתוך קובץ הקוד הזה.

const

נתוני האייקון אינם אמורים להשתנות בזמן הריצה.

uint8_t

כל איבר במערך הוא בית אחד, כלומר 8 ביטים.

[]

זוהי רשימה רציפה של ערכי הבתים שמרכיבים את האייקון.

### איך יוצרים אייקון חדש?

ציירו רשת של 16 שורות ו-16 עמודות.

סמנו פיקסל דולק כ-1 ופיקסל כבוי כ-0.

חלקו כל שורה לשתי קבוצות של 8 ביטים.

המירו כל קבוצה לערך Hex והכניסו את שני הערכים למערך.

✏️

#### דוגמה לשורה חדשה

השורה ....########.... הופכת לבינארי 00001111 11110000, ולכן בקוד נכתוב 0x0F, 0xF0.

🚀

## אתגר בונוס - לא חובה

החלפה כפולה: תנו ל-Robot את האייקון של Monster ול-Monster את האייקון של Robot.

אתגר מתקדם: נסו לצייר אייקון חדש משלכם. כל אייקון הוא רשת של 16x16 פיקסלים, שבה כל פיקסל דלוק או כבוי. הנתונים נארזים כזוג בייטים לכל שורה, ובסך הכול 32 בייטים לאייקון.

🧠

#### רמז למתקדמים

יצירת אייקון חדש דורשת עבודה עם מספרים בינאריים והקסדצימליים. כדאי לבצע את החלק הזה יחד עם המדריך או המדריכה.

מדריך עבודה לסדנת ג'וקבוקס - ניתן לפתוח בדפדפן, להקרין או להדפיס

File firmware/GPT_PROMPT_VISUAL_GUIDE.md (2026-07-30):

# פרומפט ל-GPT: יצירת גרסה מעוצבת של מדריך התרגיל

הדבק את התוכן שבין שתי השורות המפרידות ("---") לתוך ChatGPT (עדיף עם יכולת ליצור HTML/קנבס, כמו GPT-4o), כדי לקבל גרסה ויזואלית/מעוצבת של [WORKSHOP_EXERCISE_PREVIOUS_SONG.md](WORKSHOP_EXERCISE_PREVIOUS_SONG.md).

אם התוצאה יוצאת כתמונה במקום HTML, אפשר לבקש בהמשך: "עכשיו תן לי את זה כקובץ HTML שאני יכול לפתוח בדפדפן ולהדפיס".

---

אתה מעצב חומרי הדרכה לסדנת אלקטרוניקה/תכנות לתלמידים (נוער, לא בהכרח מנוסים ב-C++). המטרה: לעצב מסמך/עמוד הדרכה אחד (ויזואלי, ברור, ידידותי) על בסיס תרגיל הקוד המדויק הבא — בלי לשנות את התוכן הטכני, רק לעצב ולהציג אותו בצורה נעימה יותר לעין (במקום markdown גולמי).

השפה: עברית. הקהל: תלמידים בסדנה, יושבים מול מסך/דף מודפס תוך כדי עבודה בפועל על הקוד.

עיצוב מבוקש:
- כותרת ברורה למעלה, ותת-כותרת שמסבירה את המטרה במשפט אחד.
- חלוקה ויזואלית ברורה לשלבים ממוספרים (1, 2, 3, 4) — כל שלב בתיבה/כרטיס נפרד, עם צבע או אייקון שמבדיל בין "קובץ שפותחים" ל"קוד שכותבים".
- קטעי קוד מוצגים בפונט מונוספייס בתיבה כהה (כמו IDE), עם הדגשה ויזואלית (למשל מסגרת צבעונית) על השורה שמשתנה, כדי שיהיה ברור מה בדיוק להוסיף/לשנות.
- טיפים והערות ("למה ככה ולא ככה", "שימו לב") מסומנים בעיצוב נפרד (למשל תיבת "טיפ" עם אייקון נורה, או תיבת "אזהרה" עם אייקון שונה) כדי שיבלטו מהזרימה הראשית.
- אתגר הבונוס בסוף מעוצב כתיבה נפרדת ומוזמנת ("למי שרוצה אתגר נוסף"), לא כחלק חובה מהזרימה.
- טון: מעודד, ברור, לא מפחיד — מתאים לתלמיד שרואה קוד C++ אולי בפעם הראשונה.
- פורמט פלט: עמוד HTML עצמאי אחד (או תמונה/פוסטר, לפי מה שנוח לך) שאפשר להדפיס או להקרין, לא מסמך Word.

הנה התוכן המדויק שצריך לעצב (אל תשנה את הקוד או ההסברים הטכניים, רק את העיצוב וההצגה):

---

# תרגיל סדנה: הפיכת כפתור NEXT לכפתור "שיר קודם"

## המטרה
כרגע, לחיצה על הכפתור הפיזי המחובר ל-GPIO45 (המסומן NEXT) מעבירה לשיר הבא ברשימה. במשימה הזו נשנה את ההתנהגות כך שאותו כפתור פיזי יעביר לשיר הקודם במקום. לא נוגעים בחיווט או בחומרה — רק בקוד.

## רקע: איפה ההתנהגות הזו מוגדרת
שלושה קבצים מעורבים:
1. src/main.cpp — הקובץ הראשי שרץ כל הזמן בלולאה (loop()). הוא בודק אם הכפתור הפיזי נלחץ, ואם כן — קורא לפונקציה jukeboxUI.nextSong().
2. src/JukeboxUI.h — קובץ ה-header, שם מוצהר (declared) אילו פונקציות קיימות במחלקה JukeboxUI — כולל השורה void nextSong();.
3. src/JukeboxUI.cpp — קובץ המימוש (implementation), שם באמת כתוב מה nextSong() עושה.

כדי שהכפתור יעביר לשיר קודם, נבצע 3 שינויים: נוסיף פונקציה חדשה previousSong() (הצהרה + מימוש), ואז נגרום ל-main.cpp לקרוא לה במקום ל-nextSong().

## שלב 1 — הוספת הצהרה ב-src/JukeboxUI.h
פתחו את src/JukeboxUI.h. מצאו את השורה (בערך שורה 15):
```
void nextSong();
```
הוסיפו מיד אחריה שורה חדשה, כך שיהיה:
```
void nextSong();
void previousSong();
```

## שלב 2 — הוספת המימוש ב-src/JukeboxUI.cpp
פתחו את src/JukeboxUI.cpp. מצאו את הפונקציה (בערך שורה 507):
```
void JukeboxUI::nextSong()
{
    if (songCount() > 0)
    {
        const int current = max(0, _songIndex);
        selectSong((current + 1) % songCount());
    }
}
```
מיד אחריה הוסיפו פונקציה חדשה, דומה כמעט לגמרי — רק במקום + 1 (קדימה) נשתמש ב- + songCount() - 1 (חזרה אחורה, עם "גלגול" לסוף הרשימה כשמגיעים להתחלה):
```
void JukeboxUI::previousSong()
{
    if (songCount() > 0)
    {
        const int current = max(0, _songIndex);
        selectSong((current + songCount() - 1) % songCount());
    }
}
```
טיפ (הסבר "למה"): למה + songCount() - 1 ולא סתם - 1? כי ב-C++ אופרטור ה-% (שארית) לא מתנהג יפה עם מספרים שליליים. (current - 1) % songCount() יכול לצאת שלילי אם current == 0, מה שיגרום לקריסה של הגישה למערך. הטריק + songCount() - 1 מבטיח שהתוצאה תמיד חיובית, ועדיין נותן את אותה "תזוזה של שיר אחד אחורה, עם גלגול".

טיפ נוסף: זה בדיוק אותו החישוב שכבר קיים באותו קובץ, בפונקציה handleTouch(), בטיפול בכפתור "<<" (שיר קודם) שמופיע במסך ה-HOME על מסך המגע. אפשר לחפש בקובץ ולמצוא שורה כמעט זהה — זה סימן טוב שעשיתם את זה נכון.

## שלב 3 — שינוי src/main.cpp כדי לקרוא לפונקציה החדשה
פתחו את src/main.cpp. מצאו את הבלוק שמטפל בלחיצה על כפתור NEXT (בערך שורה 155–159):
```
else if (pressed)
{
    Serial.println("[Button] NEXT pressed");
    jukeboxUI.nextSong();
}
```
שנו את השורה jukeboxUI.nextSong(); ל:
```
jukeboxUI.previousSong();
```
(אופציונלי: אפשר גם לשנות את טקסט ה-Serial.println כך שישקף את מה שבאמת קורה עכשיו — זה לא משפיע על ההתנהגות, רק על מה שמודפס ללוג).

## שלב 4 — קומפילציה, העלאה, ובדיקה
1. שמרו את כל שלושת הקבצים.
2. הריצו pio run -e esp32s3 ובדקו שאין שגיאות קומפילציה.
3. אם הכול תקין: pio run -e esp32s3 -t upload כדי להעלות לבקר.
4. בדיקה בפועל: לחצו על כפתור NEXT הפיזי — הג'וקבוקס אמור לעבור לשיר הקודם ברשימה, לא הבא.

## הערה חשובה (תיבת אזהרה/הבהרה)
התרגיל הזה משנה רק את כפתור ה-NEXT (GPIO45). כפתור ה-PLAY/PAUSE (GPIO46) ממשיך לעבוד בדיוק כמו קודם. שימו לב גם: אם משחקים בפינבול או בהוקי אוויר מלשונית ה-GAMES, שני הכפתורים משמשים כרגע כפקדי משחק ולא כ-NEXT/PLAY-PAUSE — השינוי משפיע רק כשלא משחקים במשחק (ראו את התנאי if (jukeboxUI.isPlayingGame()) ב-main.cpp).

## אתגר בונוס (לא חובה)
למי שרוצה אתגר נוסף: לנסות לגרום לאותו כפתור פיזי להתנהג אחרת בהתאם לזמן הלחיצה — לחיצה קצרה = שיר הבא (המקורי), לחיצה ארוכה = שיר קודם. רמז: תצטרכו למדוד זמן לחיצה עם millis(), בדומה לדיבאונס הקיים לכפתורים ב-main.cpp.

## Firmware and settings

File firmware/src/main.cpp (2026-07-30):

#include <Arduino.h>

#include "AudioController.h"
#include "DisplayDriver.h"
#include "JukeboxUI.h"
#include "SongLibrary.h"
#include "StatusLed.h"
#include "TouchController.h"

namespace {
uint32_t lastTouchAction = 0;
TouchPoint lastTouchPoint;
bool haveLastTouchPoint = false;

// External PLAY/PAUSE button, wired to the board's "Expansion Input Pins"
// connector (silkscreen IO45/IO46). IO46 is used instead of IO45 because
// IO45 is sampled at boot to select the flash voltage; loading it
// externally risks a boot failure. IO46 is input-only and may have no
// usable internal pull-up, so it needs an EXTERNAL pull-up resistor
// (~10k) from IO46 to 3.3V, with the button between IO46 and GND.
constexpr int PlayPauseButtonPin = 46;
constexpr uint32_t ButtonDebounceMs = 50;
int lastButtonState = HIGH;
uint32_t lastButtonChangeAt = 0;

// External NEXT button, wired to the same "Expansion Input Pins"
// connector's other pin (IO45). On this board it's wired the same way
// as the PLAY/PAUSE button (pull-up to 3.3V, button to GND) rather
// than the pull-down scheme originally documented here, so it reads
// idle = HIGH, press = LOW - the opposite of what the pull-down
// wiring would give.
//
// IMPORTANT: IO45 is sampled at boot to select flash voltage and is
// supposed to idle LOW to avoid loading that strap. Wiring it with a
// pull-up (idle HIGH) as done here is a real boot-reliability risk
// that this software-side inversion does NOT fix - the boot-time
// sample happens before any of this code runs. If boot is flaky,
// rewire IO45 with a pull-down (button to 3.3V, resistor to GND)
// instead of inverting the logic here.
constexpr int NextButtonPin = 45;
int lastNextButtonState = HIGH;
uint32_t lastNextButtonChangeAt = 0;
}

void setup()
{
    Serial.begin(115200);
    const uint32_t start = millis();
    while (!Serial && millis() - start < 2500)
    {
        delay(10);
    }

    Serial.println();
    Serial.println("=== JUKEBOX TOUCH UI ===");
    Serial.printf(
        "PSRAM: %u bytes\n",
        static_cast<unsigned>(ESP.getPsramSize()));

    if (!displayDriver.begin())
    {
        Serial.println("ERROR: display initialization failed");
        while (true)
        {
            delay(1000);
        }
    }

    touchController.begin();
    songLibrary.begin();
    audioController.begin();
    jukeboxUI.begin();
    statusLed.begin();

    pinMode(PlayPauseButtonPin, INPUT);
    pinMode(NextButtonPin, INPUT);

    Serial.println("Jukebox UI ready");
}

void loop()
{
    TouchPoint point;
    const bool touchDown = touchController.read(point);
    const uint32_t now = millis();

    if (touchDown)
    {
        const int movement =
            haveLastTouchPoint
                ? abs(static_cast<int>(point.x) -
                      static_cast<int>(lastTouchPoint.x)) +
                      abs(static_cast<int>(point.y) -
                          static_cast<int>(lastTouchPoint.y))
                : 1000;

        // Some CST9217/TDDI firmware revisions keep returning the previous
        // coordinate after release. Re-arm by time, and immediately accept a
        // clearly different coordinate. This keeps repeated taps functional
        // even when the release flag or INT line is latched.
        const bool cooldownElapsed = now - lastTouchAction >= 450;
        const bool movedToAnotherControl =
            movement >= 28 &&
            now - lastTouchAction >= 180;

        if (!haveLastTouchPoint ||
            cooldownElapsed ||
            movedToAnotherControl)
        {
            lastTouchAction = now;
            lastTouchPoint = point;
            haveLastTouchPoint = true;
            jukeboxUI.handleTouch(point);
            touchController.rearm();
            // The reset removes the current touch event. Give the finger time
            // to leave the glass before accepting the next event.
            lastTouchAction = millis();
        }
    }

    // While a game is running, these two buttons become game controls
    // instead of playback controls - both press AND release edges
    // matter there (e.g. a flipper needs to know when it's let go),
    // unlike the one-shot playback actions below which only fire on
    // press. JukeboxUI dispatches to whichever game is active.
    const int buttonState = digitalRead(PlayPauseButtonPin);
    if (buttonState != lastButtonState &&
        now - lastButtonChangeAt >= ButtonDebounceMs)
    {
        lastButtonChangeAt = now;
        lastButtonState = buttonState;
        const bool pressed = buttonState == LOW;
        if (jukeboxUI.isPlayingGame())
        {
            jukeboxUI.setButtonA(pressed);
        }
        else if (pressed)
        {
            Serial.println("[Button] PLAY/PAUSE pressed");
            jukeboxUI.togglePlayPause();
        }
    }

    const int nextButtonState = digitalRead(NextButtonPin);
    if (nextButtonState != lastNextButtonState &&
        now - lastNextButtonChangeAt >= ButtonDebounceMs)
    {
        lastNextButtonChangeAt = now;
        lastNextButtonState = nextButtonState;
        const bool pressed = nextButtonState == LOW;
        if (jukeboxUI.isPlayingGame())
        {
            jukeboxUI.setButtonB(pressed);
        }
        else if (pressed)
        {
            Serial.println("[Button] NEXT pressed");
            jukeboxUI.nextSong();
        }
    }

    audioController.update();
    jukeboxUI.update();
    statusLed.update();
    delay(12);
}

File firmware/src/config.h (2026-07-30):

#pragma once

// ============================================================
//  WiFi Access Point
// ============================================================
#define AP_SSID      "Jukebox-ESP32"
#define AP_PASSWORD  "12345678"
#define AP_IP_1      192
#define AP_IP_2      168
#define AP_IP_3      4
#define AP_IP_4      1

// ============================================================
//  SD Card – SPI mode
//  Adjust to match your board's SD card wiring.
//  Common pins on Sunton / SC-series ESP32-S3 3.5" boards:
//    MOSI=11, MISO=13, SCLK=12, CS=10
// ============================================================
#define SD_CS_PIN    10
#define SD_MOSI_PIN  11
#define SD_MISO_PIN  13
#define SD_SCLK_PIN  12
#define SD_SPI_FREQ  25000000   // 25 MHz – lower to 4000000 if SD errors

// ============================================================
//  Audio – I2S (ESP32-S3 has no analog DAC like the original ESP32)
//  Adjust to match your board's I2S amplifier wiring.
//  TODO: Set correct pins once real audio is wired up.
// ============================================================
#define I2S_BCLK_PIN   17
#define I2S_WS_PIN     18
#define I2S_DOUT_PIN    8

// ============================================================
//  Storage Paths
// ============================================================
#define SONGS_FOLDER      "/songs"
#define PLAYLISTS_FOLDER  "/playlists"
#define SETTINGS_FOLDER   "/settings"
#define SETTINGS_FILE     "/settings/settings.json"

// ============================================================
//  Audio Defaults
// ============================================================
#define DEFAULT_VOLUME    18
#define MAX_VOLUME        30
#define MIN_VOLUME        0

// ============================================================
//  System
// ============================================================
#define SERIAL_BAUD       115200
#define MAX_LOG_ENTRIES   50
#define STATUS_POLL_MS    2000

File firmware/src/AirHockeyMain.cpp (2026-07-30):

// Standalone air hockey firmware (pio run -e airhockey -t upload) —
// flash instead of the jukebox to play, then re-flash [env:esp32s3]
// afterward. All game logic lives in AirHockeyGame, shared with the
// jukebox's Games tab; this file is just the entry point.
//
// Controls: the same two physical buttons wired for the jukebox.
//   IO46 (PLAY/PAUSE, idle HIGH / press LOW) -> paddle up
//   IO45 (NEXT,       idle HIGH / press LOW) -> paddle down
//   (IO45 is wired the same way as IO46 on this board - pull-up,
//   button to GND - not the pull-down scheme its boot-strap role
//   would normally call for. See the comment in main.cpp.)
#include <Arduino.h>
#include <esp_random.h>

#include "AirHockeyGame.h"
#include "DisplayDriver.h"

namespace {
constexpr int UpButtonPin = 46;
constexpr int DownButtonPin = 45;
}  // namespace

void setup()
{
    Serial.begin(115200);
    const uint32_t start = millis();
    while (!Serial && millis() - start < 1500)
    {
        delay(10);
    }
    Serial.println();
    Serial.println("=== AIR HOCKEY ===");

    randomSeed(esp_random());
    pinMode(UpButtonPin, INPUT);
    pinMode(DownButtonPin, INPUT);

    if (!displayDriver.begin())
    {
        Serial.println("ERROR: display initialization failed");
        while (true)
        {
            delay(1000);
        }
    }

    airHockeyGame.begin();
}

void loop()
{
    airHockeyGame.setMoveUp(digitalRead(UpButtonPin) == LOW);
    airHockeyGame.setMoveDown(digitalRead(DownButtonPin) == LOW);
    airHockeyGame.update();
    airHockeyGame.draw(displayDriver.canvas());
    displayDriver.flush();
    delay(20);
}

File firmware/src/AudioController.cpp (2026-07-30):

#include "AudioController.h"

#include <AudioFileSourceFS.h>
#include <AudioGenerator.h>
#include <AudioGeneratorMP3.h>
#include <AudioGeneratorWAV.h>
#include <SD_MMC.h>

#include "Es8311Codec.h"
#include "JukeboxAudioOutput.h"

AudioController audioController;

bool AudioController::begin()
{
    Serial.println("[Audio] Initializing ES8311 audio path...");

    _mutex = xSemaphoreCreateMutex();
    if (!_mutex)
    {
        Serial.println("[Audio] ERROR: cannot create audio mutex");
        return false;
    }

    if (!es8311Codec.begin())
    {
        Serial.println("[Audio] ERROR: ES8311 codec not found");
        return false;
    }

    _output = new JukeboxAudioOutput(es8311Codec);
    if (!_output)
    {
        Serial.println("[Audio] ERROR: cannot allocate I2S output");
        return false;
    }
    setVolume(_volume);

    const BaseType_t taskResult = xTaskCreatePinnedToCore(
        audioTaskEntry,
        "jukebox_audio",
        8192,
        this,
        2,
        &_task,
        0);
    if (taskResult != pdPASS)
    {
        Serial.println("[Audio] ERROR: cannot create playback task");
        delete _output;
        _output = nullptr;
        return false;
    }

    _ready = true;
    Serial.println("[Audio] Ready: MP3/WAV -> I2S -> ES8311 -> speaker");
    return true;
}

bool AudioController::play(const String& path)
{
    if (!_ready || !_mutex || !_output)
    {
        Serial.println("[Audio] Play rejected: audio is not ready");
        return false;
    }

    xSemaphoreTake(_mutex, portMAX_DELAY);
    stopLocked(true);

    _source = new AudioFileSourceFS(SD_MMC, path.c_str());
    if (!_source || !_source->isOpen())
    {
        Serial.printf("[Audio] ERROR: cannot open %s\n", path.c_str());
        delete _source;
        _source = nullptr;
        xSemaphoreGive(_mutex);
        return false;
    }

    String lowerPath = path;
    lowerPath.toLowerCase();
    if (lowerPath.endsWith(".mp3"))
    {
        _decoder = new AudioGeneratorMP3();
    }
    else if (lowerPath.endsWith(".wav"))
    {
        _decoder = new AudioGeneratorWAV();
    }

    if (!_decoder)
    {
        Serial.printf("[Audio] ERROR: unsupported file %s\n", path.c_str());
        delete _source;
        _source = nullptr;
        xSemaphoreGive(_mutex);
        return false;
    }

    _output->SetGain(static_cast<float>(_volume) / 100.0f);
    if (!_decoder->begin(_source, _output))
    {
        Serial.printf("[Audio] ERROR: decoder failed for %s\n", path.c_str());
        delete _decoder;
        delete _source;
        _decoder = nullptr;
        _source = nullptr;
        _output->stop();
        xSemaphoreGive(_mutex);
        return false;
    }

    _elapsedBeforeResumeMs = 0;
    _resumeStartedAt = millis();
    _paused = false;
    _playing = true;
    _trackEnded = false;
    Serial.printf("[Audio] Playing: %s\n", path.c_str());
    xSemaphoreGive(_mutex);
    return true;
}

void AudioController::pause()
{
    if (!_mutex)
    {
        return;
    }

    xSemaphoreTake(_mutex, portMAX_DELAY);
    if (_decoder && _playing)
    {
        _elapsedBeforeResumeMs += millis() - _resumeStartedAt;
        _playing = false;
        _paused = true;
        es8311Codec.setAmplifier(false);
        Serial.println("[Audio] Paused");
    }
    xSemaphoreGive(_mutex);
}

void AudioController::resume()
{
    if (!_mutex)
    {
        return;
    }

    xSemaphoreTake(_mutex, portMAX_DELAY);
    if (_decoder && _paused)
    {
        _resumeStartedAt = millis();
        _paused = false;
        _playing = true;
        es8311Codec.setAmplifier(true);
        Serial.println("[Audio] Resumed");
    }
    xSemaphoreGive(_mutex);
}

void AudioController::stop()
{
    if (!_mutex)
    {
        return;
    }

    xSemaphoreTake(_mutex, portMAX_DELAY);
    stopLocked(true);
    xSemaphoreGive(_mutex);
    Serial.println("[Audio] Stopped");
}

void AudioController::setVolume(int volume)
{
    _volume = constrain(volume, 0, 100);
    if (_output)
    {
        _output->SetGain(static_cast<float>(_volume) / 100.0f);
    }
    Serial.printf("[Audio] Volume: %d%%\n", _volume);
}

uint32_t AudioController::elapsedSeconds() const
{
    uint32_t elapsed = _elapsedBeforeResumeMs;
    if (_playing)
    {
        elapsed += millis() - _resumeStartedAt;
    }
    return elapsed / 1000;
}

void AudioController::stopLocked(bool resetElapsed)
{
    if (_decoder)
    {
        if (_decoder->isRunning())
        {
            _decoder->stop();
        }
        delete _decoder;
        _decoder = nullptr;
    }

    if (_output)
    {
        _output->stop();
    }

    delete _source;
    _source = nullptr;
    _playing = false;
    _paused = false;
    if (resetElapsed)
    {
        _elapsedBeforeResumeMs = 0;
        _resumeStartedAt = 0;
    }
}

void AudioController::audioTaskEntry(void* context)
{
    static_cast<AudioController*>(context)->audioTask();
}

void AudioController::audioTask()
{
    while (true)
    {
        bool active = false;
        xSemaphoreTake(_mutex, portMAX_DELAY);
        if (_decoder && _playing && !_paused)
        {
            active = true;
            if (!_decoder->loop())
            {
                if (_playing)
                {
                    _elapsedBeforeResumeMs += millis() - _resumeStartedAt;
                }
                Serial.println("[Audio] End of track");
                stopLocked(false);
                _trackEnded = true;
            }
        }
        xSemaphoreGive(_mutex);

        vTaskDelay(active ? 1 : pdMS_TO_TICKS(10));
    }
}

void AudioController::update()
{
    // Playback is serviced by the dedicated audio task.
}

bool AudioController::consumeTrackEnded()
{
    if (!_mutex)
    {
        return false;
    }

    xSemaphoreTake(_mutex, portMAX_DELAY);
    const bool result = _trackEnded;
    _trackEnded = false;
    xSemaphoreGive(_mutex);
    return result;
}

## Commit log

2026-07-30 Initial open-source release: firmware, enclosure, and BOM
    Standalone ESP32-S3 touchscreen jukebox. Includes the PlatformIO
    firmware, 3D-printable/laser-cut enclosure files, full bill of
    materials, a Simon Says side project, and design references.
    [Cube.step, Cube.stl, ESP32_Jukebox_BOM_AliExpress_Prices_3105.xlsx]
2026-07-30 Add affiliate disclosure infrastructure for the BOM
    Prepares the repo for AliExpress affiliate links once the affiliate
    program application is approved: disclosure text in the root README
    and a new hardware/bom/README.md. No links have been swapped yet —
    the BOM spreadsheet itself is left untouched (it contains an
    embedded Excel Table, images, and comment metadata that a scripted
    edit could corrupt).
2026-07-30 Add build photos/video, wiring diagram, and a plain-text BOM
    - media/: five build photos and a demo video, added to the README
    gallery and hero image
    - firmware/docs/board-wiring.png: moved the board pinout screenshot
    here (was the unused README hero) and linked it from the Pin
    Configuration section
    - hardware/bom/COMPONENTS.md: Markdown component list generated from
    the English BOM spreadsheet, so it reads directly on GitHub without
    opening Excel
    - hardware/bom/ESP32_Jukebox_BOM_English_Open_Source.xlsx: added the
    English BOM alongside the original Hebrew working copy; recovered
    the ESP32 board's purchase link, which was a native Excel hyperlink
    that didn't survive the Hebre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
    [ESP32_Jukebox_BOM_English_Open_Source.xlsx]
2026-07-30 Update raw-enclosure photo with the user's cropped/edited version
2026-07-30 Credit Boxes.py for the enclosure base geometry
    The enclosure panels started from Boxes.py-generated geometry before
    being modified for this project. Boxes.py is GPLv3-licensed.
